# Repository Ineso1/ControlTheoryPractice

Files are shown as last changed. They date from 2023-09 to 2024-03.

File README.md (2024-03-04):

# ControlTheoryPractice

# Linear Axis Control with PID

## Overview
This repository contains the resources and codebase for implementing a PID (Proportional-Integral-Derivative) controller on a linear axis. The project includes simulation models, MATLAB scripts, mechanical design files, Arduino code, and documentation including slides and a PDF report.

## Contents
- **Simulink Models**: Contains the simulation files for the PID control in Simulink.
- **MATLAB Scripts**: Includes MATLAB scripts used for designing and testing the PID controller.
- **Mechanical Files**: CAD files and other mechanical design documents for the linear axis.
- **Arduino Code**: Source code for the Arduino microcontroller to implement the PID control in real hardware.
- **Documentation**: Presentation slides and a detailed PDF report explaining the project's goals, design, and results.

## Getting Started
To get started with this project, you will need MATLAB, Simulink, and an Arduino IDE installed on your computer. Additionally, access to CAD software is necessary to view or modify the mechanical files.

1. Clone the repository to your local machine:
```
git clone https://github.com/Ineso1/Linear-Axis-Control.git
```
2. Open the MATLAB scripts to understand the PID algorithm and simulation setup.
3. Load the Simulink model to simulate the PID control process for the linear axis.
4. Review the mechanical files to understand the physical setup required.
5. Upload the Arduino code to your Arduino device following the setup described in the documentation.
6. Consult the PDF report and slides for a comprehensive overview of the project objectives, design considerations, and outcomes.

## Usage
This project is intended for educational purposes and as a reference for building a PID-controlled linear axis. The code and models provided can be used as a starting point for similar control system projects or adapted to fit specific requirements.



render

planta

ControlBloques

respuestaPID

ControlBloques_lento

respuestaPID_lento

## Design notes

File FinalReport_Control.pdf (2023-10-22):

Final report

Inés Alejandro García Mosqueda A00834571

Oliver Josel Hernández Rebollar A01641922

Paul Enrique Alonso Ramírez A01634608

Analysis of Control Systems

Group 401

Tecnológico de Monterrey, Campus Guadalajara

October 21, 2023

Github Repository: https://github.com/Ineso1/Linear-Axis-Control/tree/main

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
3 Identification of The Plant | 13 Syntonization of The Control | 15 Derivation of The Difference Equation | 22 Implementation of The Control | 23 Results of the Control | 25

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
al | 2
8 Individual | 29

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
# Introduction

In this report we shall address the construction of a plant. Such a plant is a linear axis

which corresponds to a major component in several industrial machines. Furthermore, it is

known that a plant by itself is not useful if we cannot operate it. The main scope of the course is

control theory. Classic and Modern. We did not cover modern control theory, thus we use one of

the most robust and iconic ways of controlling devices, namely, PID controllers. A PID controller

is supposed to modify the system according to a given reference. Naturally, a system has to be

able to identify its current state; therefore, it must receive some sort of feedback. This is known

as a closed-loop system because it is constantly comparing a current state with a desired state

and performing the corresponding modifications to achieve the aforementioned state. The PID

controller is composed of three parts: proportional, integral, and derivative. Each of these parts

play a crucial role in the actuating action because they compensate for disturbances. For

instance, if one exclusively uses a proportional controller, it would be impossible to reach the

reference because it is mathematically impossible. Thereby, we add an integral component

which allows us to approach the reference, but slows down the steady state time. If the system

experiences abrupt disturbances, we must add the derivative part which smooths aggressive

changes in the control. The three parts have a special purpose. However, it is noted that all of

them come with certain costs. To obtain a desired controller, one must carefully tune the gains

based upon a given set of performance characteristics that will be determined by the application

or customer.

All of these things will be developed in the remaining sections of the document. The

main idea is that the reader, if desired, can replicate what we have done. Also, it should be

mentioned that our implementation is not perfect but tolerable. This means that if someone

intends to build a plant, it is recommended that he or she looks for ways to improve. We thank

the professors of the course for their support during the development of the linear axis

# Objective

The objective of this document is to demonstrate one of several applications that the

control apparatus has. We have restricted the application to classical control theory on a linear

axis which is a component from a CNC or computer numerical control. We shall use a PID

controller that was briefly described in previous paragraphs. Also, we apply basic methodologies

from other disciplines such as mechanical, electrical and software engineering. Likewise, we

used some tools from digital control because it is known that one cannot simply port a controller

in continuous time to the microprocessor. Thus, one has to provide an analogous representation

for discrete time. Lastly, we expect to extend the control techniques to complex

electromechanical systems.

# State of The Art

Computer Numerical Control is a way to instruct manufacturing machinery with a

computer. It is a method widely used in the operation of industrial robots. Commonly, the

instructions for the machinery will come from software known as computer-aided design. One

basic type of CNC is point-to-point. Here the tool executes a set of primitive instructions such as

carving a path given its initial and final point. Memory is required to keep track of the performed

commands (Britannica, 2023).

Linear actuators provide, as the name suggests, motion in a straight line. There are several

ways in which one can achieve linear motion. However, we shall devote our attention to the

conversion from rotary motion to linear motion. A way to achieve this is by using screw threads

to a rotary motion source. The present project utilizes a lead screw. A lead screw has helical

threads that are designed for minimum backlash to allow precise positioning. The rotary motion

of the lead screw is translated into the nut’s linear motion. The torque required to move the nut will largely depend on the nature of the application (Figliola & Beasley, 2011). The following

image better depicts the given description.

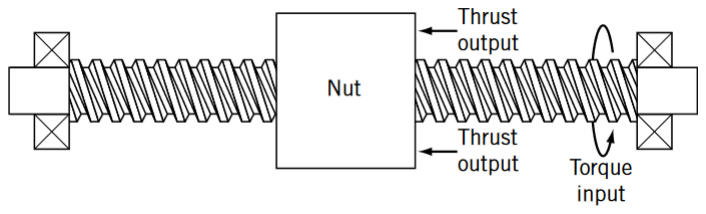
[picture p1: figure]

# Theoretical Framework

As mentioned, lead screws are a way to transmit power in modern machines. They can

generate high forces with a small moment. Also, they are known for providing a really good level

of motion precision. Thus, we see them extensively in applications that use linear actuators or

linear stages. Typically lead screws can operate in two different ways. The first one is by

supplying power to the nut and the other one is by rotating the shaft. Thereby, transferring

power to the nut. In our project, the second way was used in the project. In other words, the

nut’s rotational motion is restricted and the screw shaft rotates. As a consequence the nut

moves along the screw axis, namely, converting the rotary motion into linear motion. There are a

few advantages of lead screws worth noting. Overall, they are cheap and reliable as their

construction is simple; they require little to no maintenance; operations are smooth and reliable;

load capacity is high (Slid, 2022).

H-bridge is a special circuit configuration that allows control over the current source to a load.

This is specially important in motor applications because it is possible to change the behavior of

the motor with an H-bridge. One must be careful always guaranteeing the correct H-bridge

configurations because it is possible to cause a short circuit and damage the component (Franz,

2023). Operation in an H-Bridge is with switches. When using H-Bridge, one must consider at all

times the switches characteristics and the thermal management of the circuit. Ignoring these

properties can lead to operation failure. As mentioned, H-Bridges are heavily utilized in motor

applications, since they can be mixed with the Pulse Width Modulation, hence, controlling the

motor’s speed (Electricity - Magnetism, n.d.).

An encoder is a sensor that retrieves physical variables. As with almost every known sensor,

encoders convert what they sense into an electrical signal that can later be processed and

handled by a piece of software. These devices help to determine the position, speed and

direction. This is achieved by a count that the encoder generates and sends it to a controller.

There are several technologies that an encoder can use to create a signal; for example,

mechanical, magnetic, resistive and optical. Optical is the most common way. Specifically, The

light emitted from a source is periodically interrupted by a disk with holes. These interruptions

are the ones we use to generate the pulses and then know things like the direction of the

encoder, speed, among others (Encoder Products Company, n.d.).

# Construction of The Plant

## Mechanics

The linear shaft is a long rod-shaped tool used to support linear motion, especially

sliding motion. Without it, we wouldn't complete a sliding mechanism with linear power

transmission.

However, manufacturing and selecting the right linear shaft can be complicated. Linear shafts

can have different structures and be made from various materials, depending on the required

properties. With a linear shaft, motion can be guided and adjusted.

The load and specific requirements determine the size and precision of the linear shaft. In linear

power transmission mechanisms, the shaft works alongside an actuator, a support rail, bushings

(ball bearings), etc. In linear power transmission, the actuator typically does all the sliding work,

while the rail, bushings, and linear shafts provide support.

The screw rotates clockwise, causing the shaft, which is essentially a nut on the screw, to move

up and down the screw as the screw rotates. This is what converts the rotational motion of the

electric motor into linear motion. Linear motors have been designed to produce high force at low

speeds and even when stationary. Their design is not based on power but purely on force.

The direct current motor, also known as the direct current motor, is designed to transform

electrical energy into mechanical energy, causing rotary motion. This is made possible thanks to

the magnetic field that composes it, which is perhaps the most important part of the whole

equipment. However, it requires other components to operate effectively, such as the stator,

which serves as mechanical support for the device and holds the machine's poles, which can be

wound with copper wire around an iron core or permanent magnets. The rotor is a cylindrical

instrument with a winding and a core, which are supplied with direct current through the

collector formed by commutator segments. The commutator segments are made of copper and

are in contact with the fixed brushes.

There are two ways to mount the linear shaft: continuous support and end support. Continuous

support shafts are generally used for heavier loads, while those supported at both ends are

used for lighter loads.

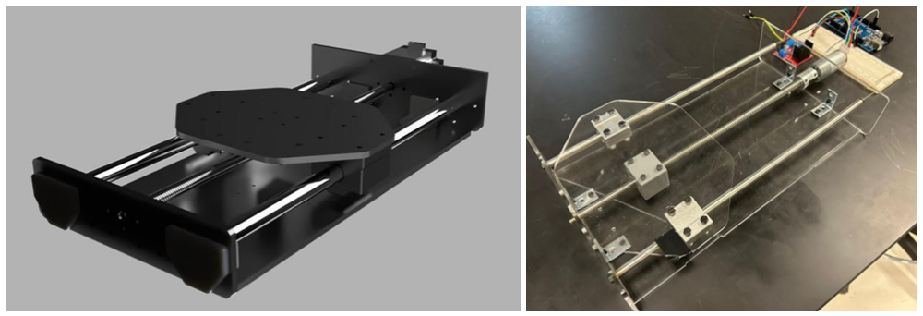
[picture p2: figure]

## Electronics

In the realm of the Linear Axis, where precision is paramount, our electronic components

serve as the central nervous system, orchestrating every facet of movement and control. This

electronic symphony relies on a harmonious ensemble of key components, each playing a

unique and indispensable role.

The L298N motor driver plays a critical role in our Linear Axis Control Project, serving as the

primary component to translate electronic signals into precise physical motion. This integrated

circuit, known for its versatility and reliability, acts as the conductor for the motor's performance.

The main function of the L298N motor driver is essential to our system, serving three main

functions:

- Direction Control: The motor driver manages the motor's direction by reversing the

polarity of the applied voltage to achieve forward or reverse motion.

- Speed Regulation: It allows us to adjust the motor's speed by varying the supplied

voltage, providing us with the capability for precise speed control.

- Current Management: It incorporates current-sensing circuits to prevent overcurrent

conditions, protecting both the motor and the driver itself.

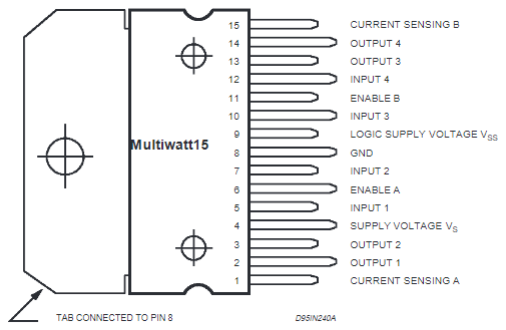
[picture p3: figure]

At the core of our project's electronics is the Arduino Mega, a microcontroller board based on

the ATmega2560. This microcontroller serves as the project's central processing unit, executing

complex control algorithms and facilitating seamless communication with various sensors and

components. The choice of Arduino Mega contributes to the project's user-friendliness and

versatility, making it an ideal candidate for orchestrating the multi-disciplinary aspects of our

linear axis control system.

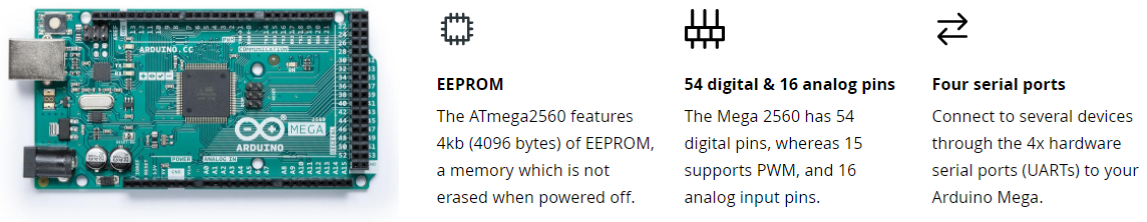
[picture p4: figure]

The motor-reducer assembly seamlessly integrates a motor, reduction gearbox, and encoder, a

trio of components that harmonize to deliver precise control over the linear motion of our axis. At

the core of this assembly is the motor, strategically coupled with a reduction gearbox. Together,

they form a symbiotic relationship, with the motor providing the mechanical power required to

propel the linear motion. The reduction gearbox, with an approximate reduction ratio of 1:45,

transforms the motor's high-speed rotation into the slower, high-torque movement essential for

our project's precision. Nestled within this assembly is the encoder, a sentinel of precision. This

vital component employs Hall Effect technology and boasts a resolution of approximately 493.9

PPR (Pulses Per Revolution) with a ±10% tolerance. Operating within a voltage range of 3.3V to

5V and offering a response frequency of 100 kHz, the encoder delivers real-time feedback that

is instrumental in our pursuit of accuracy. The motor, reduction gearbox, and encoder operate in

tandem to orchestrate the linear motion of our axis. As the motor churns, the gearbox tempers

its high-speed rotation, allowing for controlled movement. Simultaneously, the encoder diligently

records every aspect of this motion—position, speed, and direction. This trove of data serves as

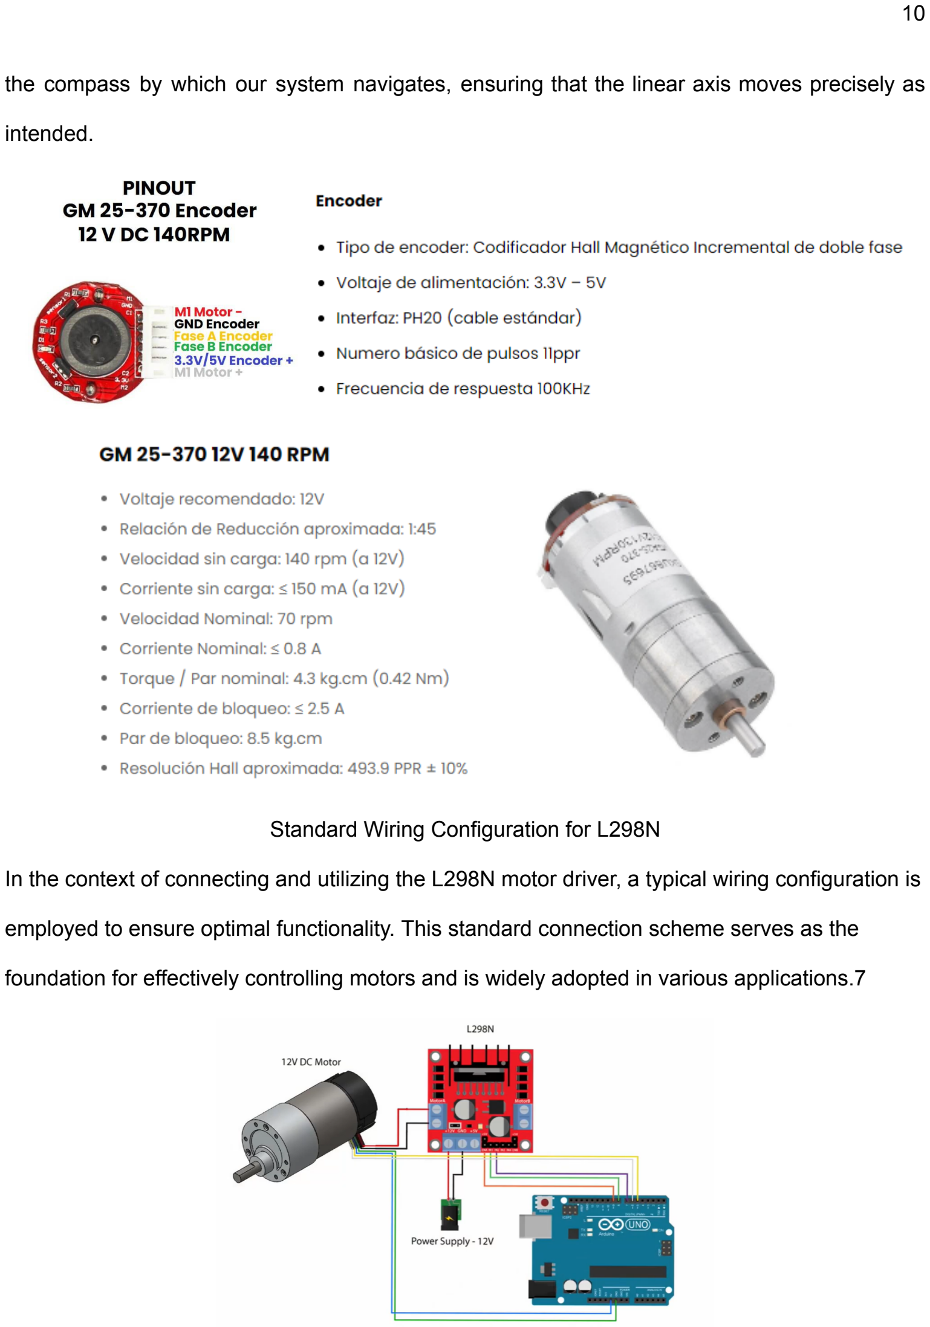
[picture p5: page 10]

the compass by which our system navigates, ensuring that the linear axis moves precisely as

intended.

Standard Wiring Configuration for L298N

In the context of connecting and utilizing the L298N motor driver, a typical wiring configuration is

employed to ensure optimal functionality. This standard connection scheme serves as the

foundation for effectively controlling motors and is widely adopted in various applications.7

## Software

The software we developed is quite simple because we were instructed to use an

Arduino which is known for being user friendly. We wanted to increase the portability and

robustness of our design, so we implemented a class called PositionMotorControl. This class

has five methods for orchestrating the motor’s behavior. The constructor will retrieve all the

information for the member functions. Initialization method will send the constructor’s data to the

Arduino. Control method will be rotating the shaft based upon an error computed using the

number of pulses. Set Target Position receives the desired position in the number of pulses. Get

Current Position returns the current position attribute and Set Cero establishes what will be

taken as the reference, namely, the origin. Attributes declared with the volatile qualifier are used

in the interruption called Handle Encoder. This private function member reads the encoder in

real time and updates things like current position and the motor’s direction. It is declared as

static and thus uses a pointer to be called. At the beginning of the main program we create a

motor instance, then set the baud rate to communicate with the microcontroller. Lastly we enter

the loop and read the Serial Monitor to receive input from the user, if that does not happen, we

print the position. Later the control method is called and moves the nut to the desired position.

The reason of this implementation is:

- Initialization: One of the key features of the 'PositionMotorControl' class is its initialization

process. We utilize the 'init()' method to initialize the motor and encoder pins, thereby

configuring the necessary parameters for control. This step is vital in preparing the

system for precise motion control.

- Control Methods: The class incorporates various control methods, notably 'control()' and

'controlPID()', which enable us to fine-tune the motor's behavior to meet our specific needs. These methods play a pivotal role in ensuring the motor's responsiveness and

adaptability to different control strategies.

- Position and Velocity: Within our software, we can set the target position, monitor the

current position, and adjust the motor's velocity as required. This capability allows us to

precisely control the motion of our linear axis, making it responsive to real-world

demands.

- Error Handling: Error handling is an integral part of our software. We utilize variables

such as 'error' and 'errores' to precisely manage and respond to any deviations from the

desired path. These mechanisms contribute to the system's accuracy and robustness.

- Hardware Integration: The class seamlessly integrates with the hardware by working

with motor pins, supporting encoder feedback, and incorporating mechanical constants.

This integration ensures accurate and controlled motion. Mechanical constants such as

gear ratios and encoder resolutions are considered to convert between pulses and

real-world positions.

- Interrupt Handling: Our software employs interrupt-driven functions to manage encoder

changes efficiently. By doing so, we enhance the overall efficiency of our system,

enabling rapid response to position changes and contributing to the system's stability.

- Custom Libraries: To streamline and encapsulate the functionality, we have developed

custom libraries, 'PositionMotorControl.h' and 'PositionMotorControl.cpp'. These libraries

simplify the integration of motor control into our project and promote code modularity.

The following is a high-level description of the main program. The control method is responsible

for rotating the shaft based on an error computed using the number of pulses.

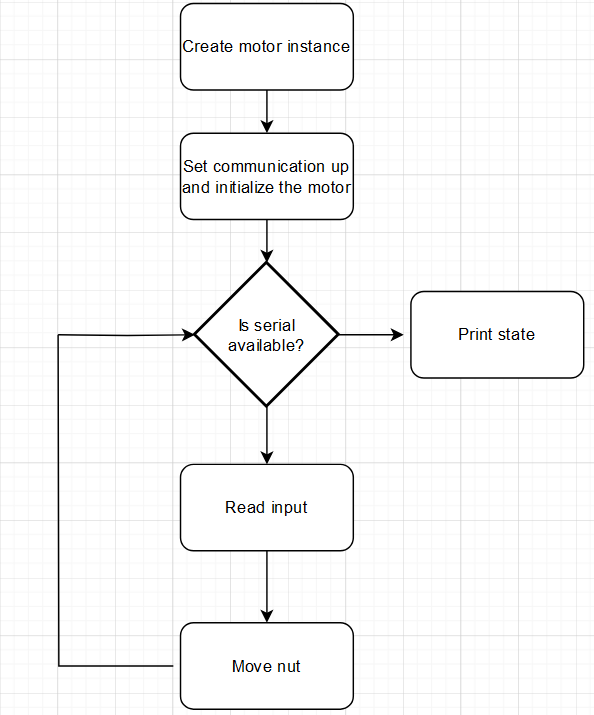
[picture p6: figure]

# Implementation of The System

## Identification of The Plant

Identifying the plant means creating a mathematical or empirical model that describes the

behavior of the system. This model helps us understand how the system responds to different

inputs and disturbances. Without a proper model, it's challenging to predict or explain system

behavior accurately. Knowing the plant is fundamental for designing effective control systems.

Engineers need to understand the dynamics of the system to design controllers that can

regulate it optimally. Control algorithms often rely on an accurate model of the plant to determine

control actions. This helps us to optimize the performance of the system. By understanding the

plant's response characteristics, we can fine-tune control strategies to achieve desired

performance metrics, such as stability, speed, accuracy, and robustness. Plant identification

allows us to optimize the performance of the system. By understanding the plant's response

characteristics, we can fine-tune control strategies to achieve desired performance metrics,

such as stability, speed, accuracy, and robustness.

We implemented a systematic and data-driven process, leveraging carefully designed code to

uncover the dynamic behavior of our motor.

Data Acquisition

The initial phase of our plant identification process entailed the collection of extensive data. We

aimed to create a comprehensive dataset that allowed us to explore how the motor system

responded to varying input signals. To accomplish this, we employed a controlled

experimentation approach. We applied a range of PWM (Pulse Width Modulation) signals to the

motor while simultaneously measuring and recording the corresponding encoder output. This

process was carried out at consistent time intervals to ensure that we obtained a precise and

reliable dataset. The data acquisition step was pivotal in capturing the dynamic response of our

motor system under a variety of operating conditions. It allowed us to observe the system's

behavior as it adapted to different control inputs, providing valuable insights into its

characteristics.

Regression Analysis

With our dataset in hand, we turned to the tools offered by MATLAB's System Identification

Toolbox. This software environment provided us with the means to perform advanced data

analysis, model fitting, and system identification. Through the application of regression analysis

techniques, we embarked on the task of approximating the plant function that governs the behavior of our motor system. This function represents the mathematical relationship between

the input (PWM signals) and the output (encoder responses) of the system. Our objective was

to develop a mathematical model that could accurately describe and predict the motor's

behavior under various conditions. The regression analysis process involved the exploration of

different model structures, identification of model parameters, and the validation of the resulting

model against the acquired data. By iteratively refining the model, we sought to achieve a high

level of accuracy in representing the dynamic behavior of the motor system.

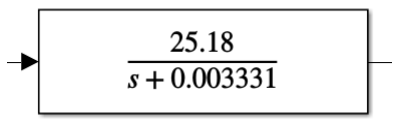
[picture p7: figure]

Access to the Code Repository for characterization of the plant

For a comprehensive understanding of our project's code and implementation, you can access

the complete source code and related resources in our GitHub repository. The code is available

at the following link:

GitHub Repository - Code for Characterization of Angular Velocity:

https://github.com/Ineso1/Linear-Axis-Control/tree/main/ControlProgram/CaracterizacionVelocid

adAngular (https://github.com/Ineso1/Linear-Axis-Control/tree/main/ControlProgram/CaracterizacionVelocidadAngular)

## Syntonization of The Control

In the realm of control systems, achieving optimal performance often necessitates the careful

adjustment and tuning of control parameters. This process, known as control tuning or

syntonization, is a pivotal step in ensuring that the control system responds accurately and

effectively to the desired setpoints and disturbances.

Importance of Control Syntonization

- Enhanced Performance: Accurate control parameter tuning can lead to improved system

performance, enabling faster response times, reduced settling times, and more precise

control of the system's behavior.

- Stability and Robustness: Proper syntonization ensures that the control system remains

stable under various operating conditions and disturbances. It prevents issues such as

overshoot, oscillations, and instability.

- Minimized Energy Consumption: Well-tuned control systems can operate more

efficiently, consuming less energy and reducing operational costs.

- Adaptation to Changing Conditions: As real-world conditions change, the control system

needs to adapt. Control syntonization allows the system to adjust to new parameters and

maintain optimal performance.

- Improved Safety: In safety-critical systems, accurate syntonization is imperative to

prevent dangerous and unexpected behavior.

- Control parameter tuning typically involves adjusting variables like proportional gain (Kp),

integral gain (Ki), and derivative gain (Kd) in a PID (Proportional-Integral-Derivative)

controller. The specific methodology and approach to syntonization depend on the

control algorithm and the characteristics of the plant.

Methods of Control Syntonization

There are various methods and techniques for control syntonization, including:

- Manual Tuning: In this method, we adjust control parameters manually based on their

knowledge and experience. It's a trial-and-error approach that may require multiple

iterations to achieve optimal results.

- Ziegler-Nichols Method: This method provides systematic guidelines for tuning PID

controllers. It involves identifying the ultimate gain and ultimate period from the system's

response to a step input.

- Frequency Response Analysis: Using frequency response techniques, we can analyze

the system's behavior to determine the optimal control parameters.

- Optimization Algorithms: Advanced techniques, such as gradient descent or genetic

algorithms, can be used to automate the syntonization process. These methods aim to

find optimal parameter values efficiently.

Our approach

In our project, we employed an analytical approach for the syntonization of the PID

(Proportional-Integral-Derivative) controller. The goal was to fine-tune the control parameters to

achieve the desired system response. Our approach primarily centered around using the

concepts of maximum impulse and steady-state time, and ultimately, partial fractions

decomposition.

To begin the syntonization process, we identified the system's ultimate gain. The ultimate gain is

the magnitude of the control signal that, when applied as a step input, induces sustained

oscillations in the system's response. The maximum impulse is a crucial parameter for the

syntonization of the controller. Concurrently, we determined the steady-state time, which

represents the period of one complete oscillation cycle under the influence of the maximum

impulse parameter. The steady-state time provides insight into the system's oscillatory behavior.

Syntonization Through Partial Fractions Decomposition

The ultimate gain and steady-state time values served as foundational information for the

syntonization process. We leveraged these parameters to derive a transfer function that accurately represented the dynamics of the system. This transfer function was critical for tuning

the PID controller. The syntonization process involved expressing the system's response as a

sum of first-order and second-order transfer functions, represented through partial fractions

decomposition. By decomposing the system into these simpler components, we could better

understand and control its response. Using the derived transfer function, we adjusted the control

parameters; Proportional Gain (Kp), Integral Time (Ti), and Derivative Time (Td to achieve the

desired system response. The insights gained from the decomposition guided us in selecting

appropriate values for these parameters to optimize the system's performance.

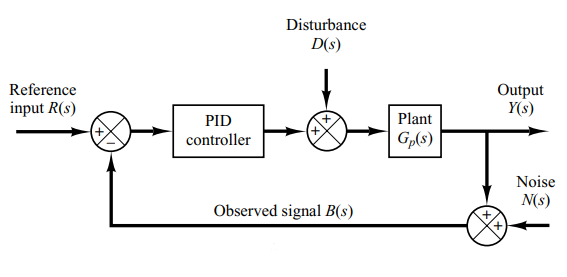
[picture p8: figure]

Advantages of Analytical Syntonization

- Theoretical Foundation: This analytical approach to syntonization is firmly grounded in

control theory and system dynamics, providing a strong theoretical basis for tuning the

controller.

- Precise Control: By using Ku and Tu to derive the transfer function and employing partial

fractions decomposition, we were able to fine-tune the control parameters with a high

degree of precision.

- Efficiency: The analytical approach is efficient and eliminates the need for extensive

trial-and-error tuning, resulting in a more streamlined and systematic syntonization

process.

In the subsequent section, we will detail the specific steps taken and results achieved through

this analytical syntonization approach. This will provide a comprehensive understanding of how

we optimized the control system to meet our project's requirements.

Certainly, you can include the second approach you used for PID tuning with MATLAB Simulink

in your report:

Alternative Approach: MATLAB Simulink PID Tuning

In addition to our analytical approach, we employed an alternative method for synchronizing the

PID (Proportional-Integral-Derivative) controller. This alternative approach involved leveraging

the capabilities of MATLAB Simulink, a powerful tool for system modeling and control design.

Using MATLAB Simulink for PID Tuning

Model Representation: In this approach, we first created a dynamic model of our system within

MATLAB Simulink. This model encapsulated the plant's behavior and its interaction with the PID

controller. In this implementation we added a PID controller block to our Simulink model. This

block allowed us to easily adjust the controller's parameters, including the Proportional Gain

(Kp), Integral Time (Ti), and Derivative Time (Td). MATLAB Simulink provides a suite of

automated tuning tools that simplify the process of optimizing the control parameters. These

tools can be especially valuable when dealing with complex systems or when a quick and efficient tuning process is required. With the PID controller block and automated tuning tools in

place, we conducted simulations to observe the system's response under various conditions.

MATLAB Simulink allowed us to visualize and analyze the system's behavior, helping us identify

the optimal control parameters. The flexibility of MATLAB Simulink allowed us to iteratively

refine the control parameters until the system's response aligned with our project's

requirements. We could easily adjust the gains and time constants in real-time during the

simulation.

Advantages of the MATLAB Simulink Approach

- User-Friendly Interface: MATLAB Simulink offers an intuitive and user-friendly interface

for control system design and tuning, making it accessible even to those with limited

control engineering expertise.

- Efficiency: The automated tuning tools within MATLAB Simulink can expedite the tuning

process, saving time and effort, especially in cases where a complex system requires

quick syntonization.

- Visual Feedback: The ability to visualize and analyze the system's response in real-time

is a significant advantage. It allows for a more intuitive understanding of the system's

behavior and control performance.

- Robustness: The automated tools in MATLAB Simulink are equipped to handle various

system responses, including overshoot, oscillations, and settling times. This ensures

robust control parameter tuning.

For an in-depth exploration of our control analysis, including detailed models, simulations, and

results, we invite you to review the complete set of resources available in our GitHub repository.

These resources provide comprehensive insights into our control strategies and methodologies,

offering a deeper understanding of our project's control system.

Unset

Access to the Code Repository for PID Analysis and Tuning

GitHub Repository - Analysis of Control:

https://github.com/Ineso1/Linear-Axis-Control/tree/main/Analisis%20de%20Control

Our analytical approach MATLAB code

#Caracteristicas del control en velocidad angular

Mp = 0.15;
psib = sqrt(((log(Mp))^2 / (pi^2))/(1 - ((log(Mp))^2 / (pi^2)))) ts = 5;
omeganb = 3/(psib*ts)
Q = 2*psib*omeganb;
T = omeganb;
(-Q + sqrt(Q^2 - 4*T))/2;
p1 = 10*Q;
A = Q + p1;
B = T + p1*Q;
C = p1*T;

#Funcio de planta y coeficientes PID

omegan = 0.01;
psi = 3;
2*psi*omegan;

kd = ((A/omegan) - 2*psi)/omegan kp = B/(omegan^2) - 1
ki = C/(omegan^2)

integ = ki/kp
deriv = kd/kp

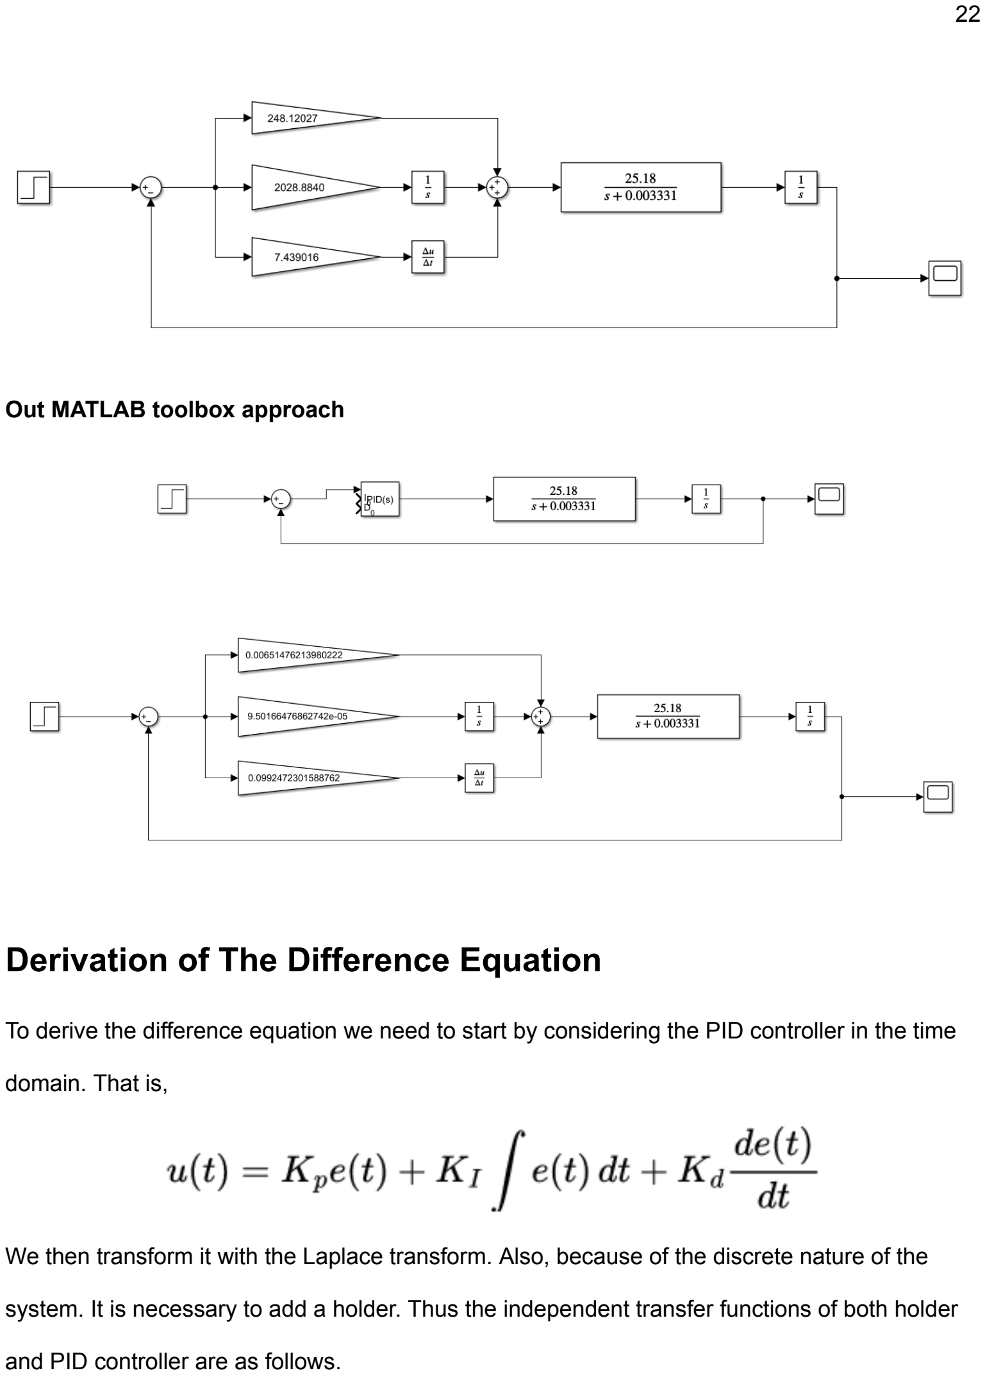
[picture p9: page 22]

Out MATLAB toolbox approach

## Derivation of The Difference Equation

To derive the difference equation we need to start by considering the PID controller in the time

domain. That is,

We then transform it with the Laplace transform. Also, because of the discrete nature of the

system. It is necessary to add a holder. Thus the independent transfer functions of both holder

and PID controller are as follows.

By using some algebra of diagrams. The output of a block is the product of the transfer function

and the input signal. Therefore, the product of both holder and PID controller is the resulting

equation.

At this point it is convenient to use the z transform because we are dealing with a discrete

implementation, so it looks like this

After the transform and some algebraic manipulation we arrive to the PID expression in

z-domain

By getting rid of the fractions and separating CV and E on different sides of the equation we

arrive to the following expression

Then, by using known formulas we perform the inverse transform and arrive to the known

difference equation form

C/C++

## Implementation of The Control

Our linear axis control system incorporates a PID (Proportional-Integral-Derivative) controller to

precisely regulate the motion of the linear axis. The PID controller plays a crucial role in

achieving the desired position while maintaining stability and responsiveness.

void PositionMotorControl::controlPID(){
error = targetPosition - (currentPosition * 2 * 3.1416 / 493.9); errores[1] = errores[0];
errores[2] = errores[1];
errores[0] = error;
prevPwm = motorSpeed;

double kp = 248;
double ki = 2300;
double kd = 7.44;
double a = (kp + kd/0.02) * errores[0];
double b = (-kp + (ki*0.02) - (2*kd/0.02)) * errores[1]; double c = (kd/0.02) * errores[2];

int pwmSpeed = prevPwm + a + b + c;
motorSpeed = pwmSpeed;

// Comparison between direction and velocity if (error <= -1) {
motorDirection = 1; // Move forward
}
else if (error >= 1) {
motorDirection = -1; // Move backward }
else {
motorDirection = 0; // Stop
pwmSpeed = 0;
}

// Motor's control
analogWrite(motorPin1, motorSpeed); digitalWrite(motorPin2, motorDirection == -1 ? HIGH : LOW); digitalWrite(motorPin3, motorDirection == 1 ? HIGH : LOW);

}

PID Parameters:

- kp (Proportional Gain): 248
- ki (Integral Gain): 2300
- kd (Derivative Gain): 7.44

PID Components:

- a: Proportional component
- b: Integral component
- c: Derivative component

This PID controller computes a new PWM speed for the motor based on the current error and

the stored error values. It adjusts the motor direction to move towards the target position while

considering the error's magnitude.

The PID implementation in our code ensures precise and stable control of the linear axis,

enabling it to accurately follow the desired trajectory. The fine-tuned PID parameters are a result

of our syntonization process, as described in previous sections. The flexibility to adjust these

parameters allows us to tailor the control system to meet specific performance requirements.

Access to the Code Repository for The full Linear Axis Control Code

For a comprehensive view of the project's implementation details, including the codebase,

models, and system setup, please explore the complete set of resources available in our GitHub

repository:

GitHub Repository - Implementation Section:

https://github.com/Ineso1/Linear-Axis-Control/tree/main/ControlProgram/LinearAxisControl_v2/C

ontrolEjeLineal_v2 (https://github.com/Ineso1/Linear-Axis-Control/tree/main/ControlProgram/LinearAxisControl_v2/ControlEjeLineal_v2)

## Results of the Control

Our PID control approach for the linear axis has yielded notable outcomes, each with distinct

characteristics. These results highlight the impact of control syntonization on the performance of

our system. We Analyze the achievements of both approaches, emphasizing the advantages

and disadvantages of quick and slow response times.

Quick Response Approach (Maximum Impulse: 15%, Steady-State Response: 0.4 seconds)

Slower Response Approach (Maximum Impulse: 1%, Steady-State Response: 2 seconds)

Advantages of a Quick Response:

- Precision: The quick response approach offers precise control, allowing the linear axis to

closely follow the desired trajectory with minimal deviation.

- Reduced Settling Time: The rapid steady-state response, achieved within 0.4 seconds,

results in a shorter settling time. This is particularly advantageous when the system

needs to reach and maintain a specific position swiftly.

- Enhanced Responsiveness: Quick response times make the system highly responsive to

changes in the input or disturbances, enhancing its ability to adapt to dynamic

conditions.

Disadvantages of a Quick Response:

- Risk of Overshoot: A rapid response may lead to overshooting, where the system briefly

exceeds the desired position before stabilizing. This can introduce oscillations or

instability.

- Increased Energy Consumption: Achieving a quick response may require higher control

efforts, potentially leading to increased energy consumption.

- Potential for Reduced System Longevity: High-speed movements can contribute to wear

and tear on mechanical components, which may reduce the system's overall longevity.

Advantages of a Slower Response:

- Stability: The slower response approach prioritizes stability, minimizing the risk of

overshoot and oscillations. This can be advantageous in systems where stability is

critical.

- Reduced Energy Consumption: Slower responses typically require less energy, making

them energy-efficient and cost-effective in the long run.

- Enhanced System Durability: Reduced stress on mechanical components can prolong

the system's lifespan, contributing to its long-term reliability.

Disadvantages of a Slower Response:

- Reduced Precision: Slower responses may result in less precise control, particularly in

applications where rapid, precise movements are required.

- Longer Settling Time: A slower steady-state response with a 2 second settling time may

not be suitable for applications that demand rapid positioning or immediate responses to

disturbances.

- Limited Responsiveness: Slower responses make the system less adaptable to dynamic

changes, potentially affecting its ability to respond swiftly to new conditions.

Balancing Act

The choice between a quick response and a slower response is a delicate balancing act. The

optimal approach depends on the specific requirements and constraints of the application. In

some cases, precision and rapid response are paramount, while in others, stability and energy

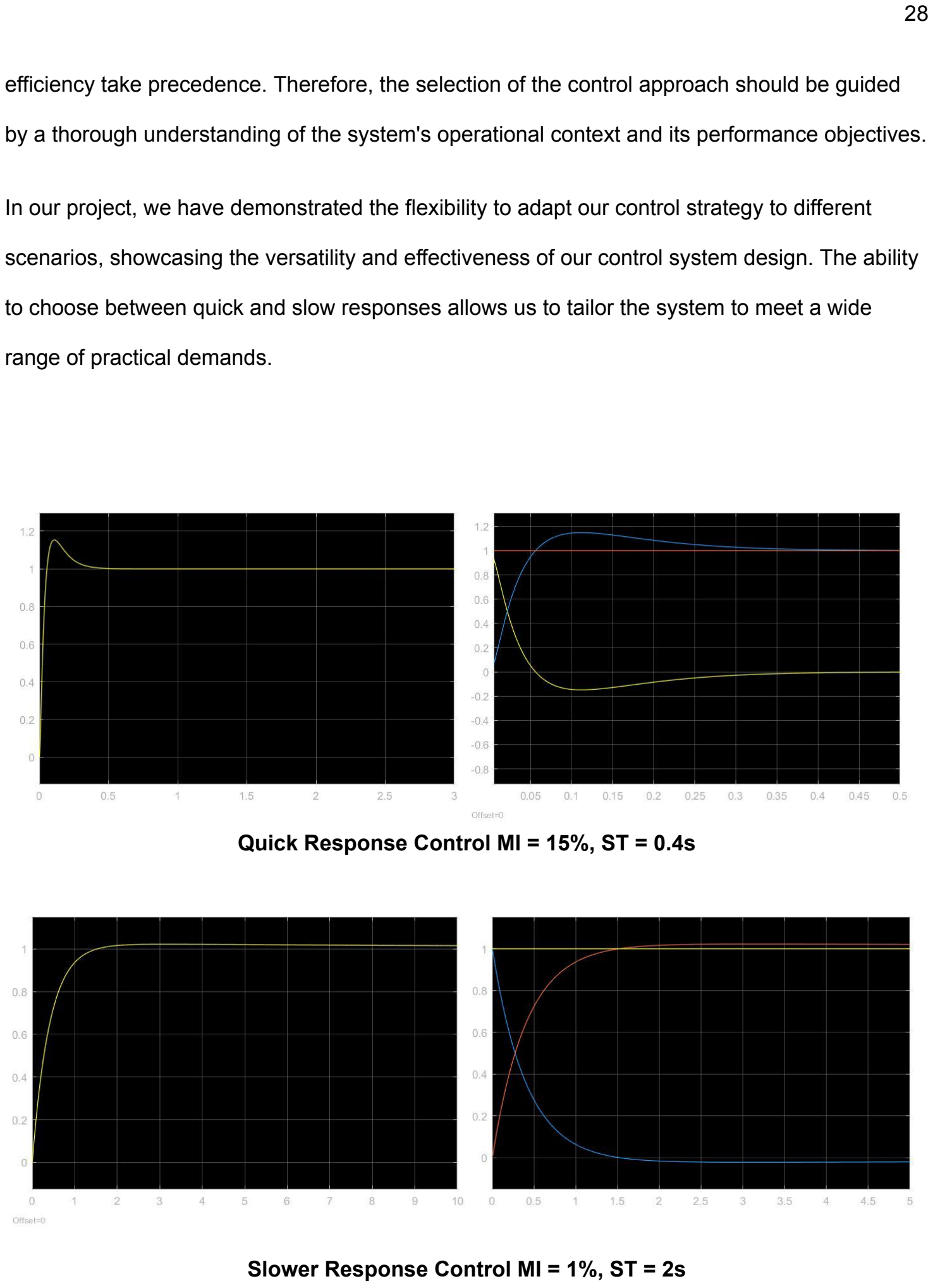
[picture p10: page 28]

efficiency take precedence. Therefore, the selection of the control approach should be guided

by a thorough understanding of the system's operational context and its performance objectives.

In our project, we have demonstrated the flexibility to adapt our control strategy to different

scenarios, showcasing the versatility and effectiveness of our control system design. The ability

to choose between quick and slow responses allows us to tailor the system to meet a wide

range of practical demands.

Quick Response Control MI = 15%, ST = 0.4s

Slower Response Control MI = 1%, ST = 2s

# Conclusion

## General

The control, mechanics and electronics of a linear axis operate to achieve precision,

speed and reliability in numerous applications ranging from industrial machinery to advanced

robotics. Mechanics provide the structural foundation and movement capabilities, driven by

electronics ensuring precise energy delivery and timing. The control system receives input from

the user or system, converts them into commands for the electronics and mechanics to execute.

In conclusion, the perfect integration of these three components is essential. Its collaborative

operation ensures efficient and accurate performance of a linear axis, which is vital to

maintaining the high standards required in today's technologically advanced environment.

## Individual

Oliver In my understanding of the control, mechanics, and electronics of a linear axis,

they work together to deliver precision, speed, and reliability in a broad spectrum of

applications, from industrial machines to cutting-edge robotics. While the mechanics give the

structural backbone and movement capabilities, the electronics are responsible for ensuring

precise power transmission and synchronization. As for the control system, I see it as the brain

that takes in user or system inputs and turns them into actionable instructions for the mechanics

and electronics. To sum it up, I believe that the flawless integration of these three elements is

critical. Their collective function ensures the efficient and precise operation of a linear axis,

which I consider essential in the high-standard, tech-driven environments of today.

Inés I've acquired a profound understanding of control theory and its practical

applications in digital systems, particularly in the discrete-time domain. The journey involved

bridging the gap between theory and real world implementation, a valuable skill in the realm of

engineering. From PID controllers to plant identification and syntonization, I've learned how to harness mathematical principles to achieve precise control. I now appreciate the beauty of

control theory in creating efficient, stable, and responsive systems. This experience has

provided me with a strong foundation in translating complex mathematical concepts into code,

enabling me to bring control theory to life in my projects. As I move forward, I feel well-equipped

to tackle diverse engineering challenges with a solid grasp of mathematics, the theory, and the

practical application of control systems in digital systems and discrete-time environments.

Paul I have learned several things over the course of 10 weeks. Most importantly, I have

realized all the things that can be done with control theory. I believe that a linear axis is just one

of the many applications of control. I am excited to see what other things can be done,

especially, in the realm of robotics which is an important and emerging field. As far as I am

concerned there are several subfields in control theory given the nature of several dynamical

systems. There will be times when it is not possible to linearize a system, so we will be forced to

look for generalized ways of modeling a system. Nevertheless, I presume this was a fairly good

introduction to control theory and some of its applications. I look forward to learning more on the

subject, and luckily enough with a more theoretical approach, as I strongly believe it is essential

to comprehend the area.

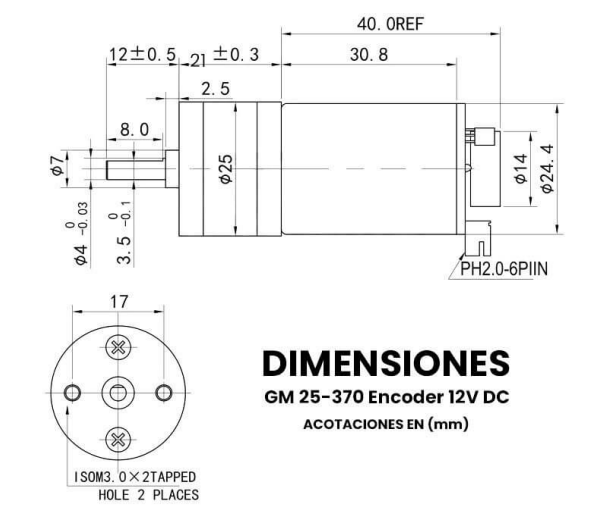
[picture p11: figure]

https://uelectronics.com/producto/gm-25-370-motor-con-encoder-12v-dc-140rpm-330rpm/

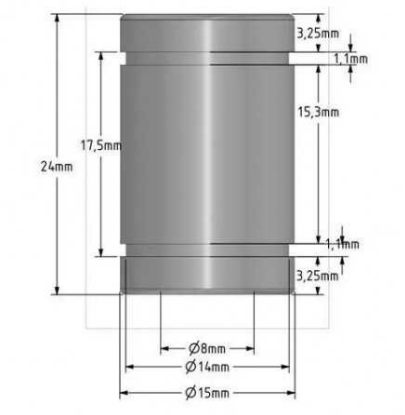
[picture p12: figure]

https://uelectronics.com/producto/balero-rodamiento-lineal-lm8uu-de-8mm-3d-cnc/

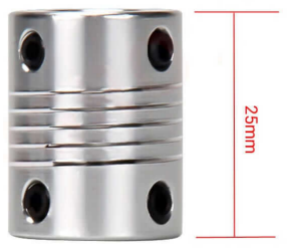
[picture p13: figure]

Etiquetas: Acoplador Nema, cople, Cople D18L25, cople flexible, Cople Flexible 5x5mm, Cople Flexible 5x8mm, Cople Flexible 6.35x8mm, Cople Flexible 8x10mm, Cople Flexible 8x8mm, Cople Flexible D18L25, D18L25, Piezas y Accesorios 3D CNC https://uelectronics.com/producto/cople-flexible-d18l25-nema-acoplador/

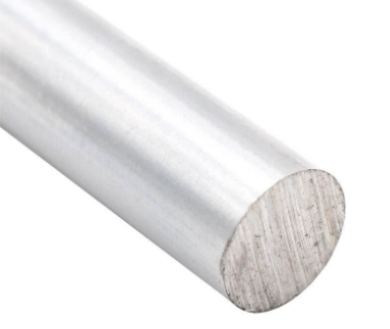
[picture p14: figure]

Varilla Lisa 8mm 60cm para Impresora 3D/CNC https://uelectronics.com/producto/varilla-lisa-8mm-para-impresora-3d-cnc/

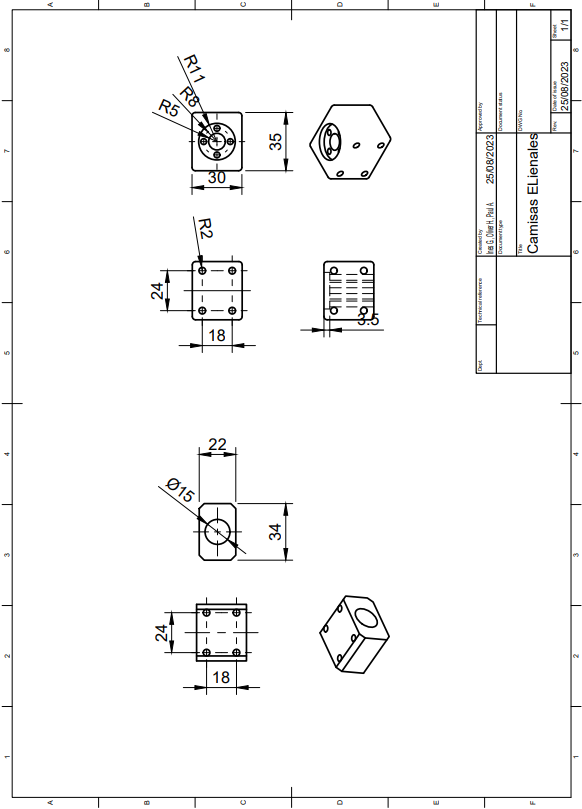
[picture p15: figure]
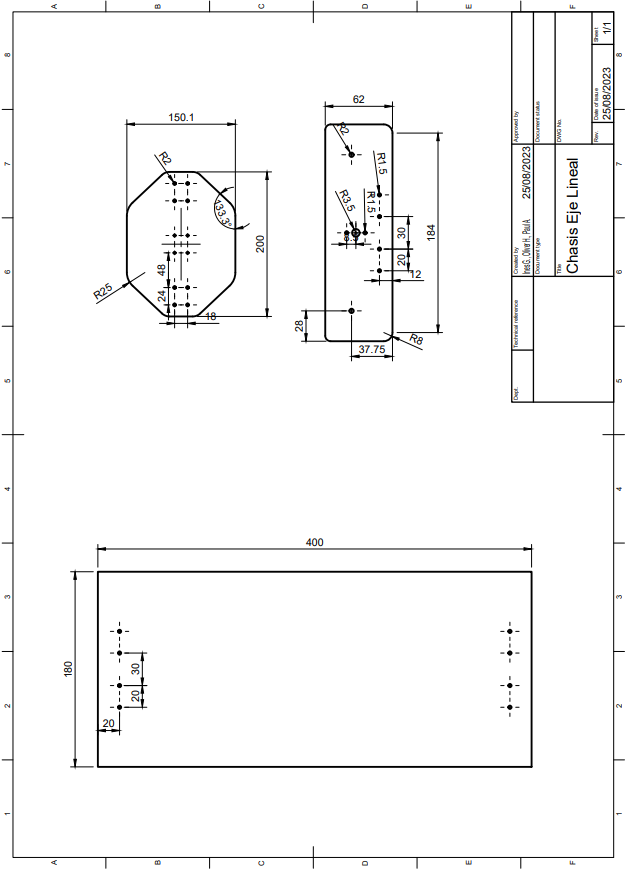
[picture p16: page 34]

# References

Britannica. (2023, May 28). Computer Numerical Control.

https://www.britannica.com/technology/numerical-control

Electricity - Magnetism. (n.d.). H-Bridges. https://www.electricity-magnetism.org/h-bridges/

Encoder Products Company. (n.d.). What is an encoder?.

https://www.encoder.com/article-what-is-an-encoder

Figliola, R., & Beasley, D. (2011). Theory and Design for Mechanical Measurements. John Wiley

& Sons, Inc.

Franz, K. (2023, April 18). What Is an H-Bridge?. https://digilent.com/blog/what-is-an-h-bridge/

Slid Siim. (2022, January 24). Lead Screws Explained. https://fractory.com/lead-screws/

Mega, A. (s/f). Arduino® MEGA 2560 Rev3. Arduino.cc. Recuperado el 10 de septiembre de

2023, de https://docs.arduino.cc/resources/datasheets/A000067-datasheet.pdf

Mega, A. (s/f). Arduino® MEGA 2560 Rev3. Arduino.cc. Recuperado el 10 de septiembre de

2023, de https://docs.arduino.cc/resources/datasheets/A000067-datasheet.pdf

Mega, A. (s/f). Arduino® MEGA 2560 Rev3. Arduino.cc. Recuperado el 10 de septiembre de

2023, de https://docs.arduino.cc/resources/datasheets/A000067-datasheet.pdf

# Appendix

## Code

https://github.com/Ineso1/Linear-Axis-Control/tree/main

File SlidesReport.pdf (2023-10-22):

## Analysis of Control Systems

Ines Garcia | Oliver Hernandez | Paul Ramirez

Tecnologico de Monterrey, Campus Guadalajara

October 20, 2023

Ines Garcia, Oliver Hernandez, Paul Ramirez | Tecnologico de Monterrey, Campus Guadalajara

Analysis of Control Systems

1 | Introduction
2 | Construction of The Plant
3 | Implementation of The System
4 | Conclusion

During the course we developed a linear axis as well as its control. Previously, we presented the construction of the plant, so now we shall devote this presentation mainly to the design and implementation of the PID control. Lastly, we will provide some of the needed theory to understand the decisions behind our plant.

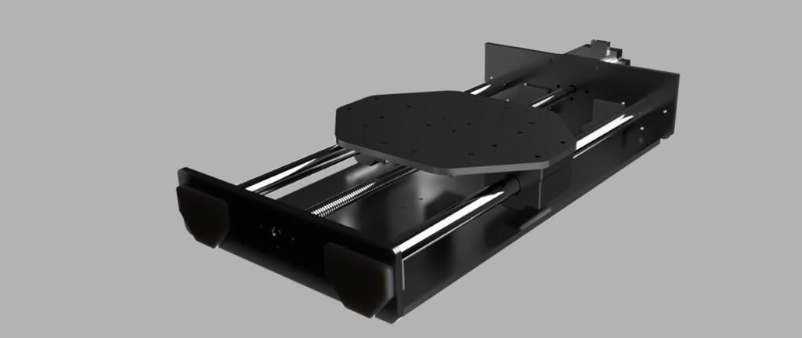
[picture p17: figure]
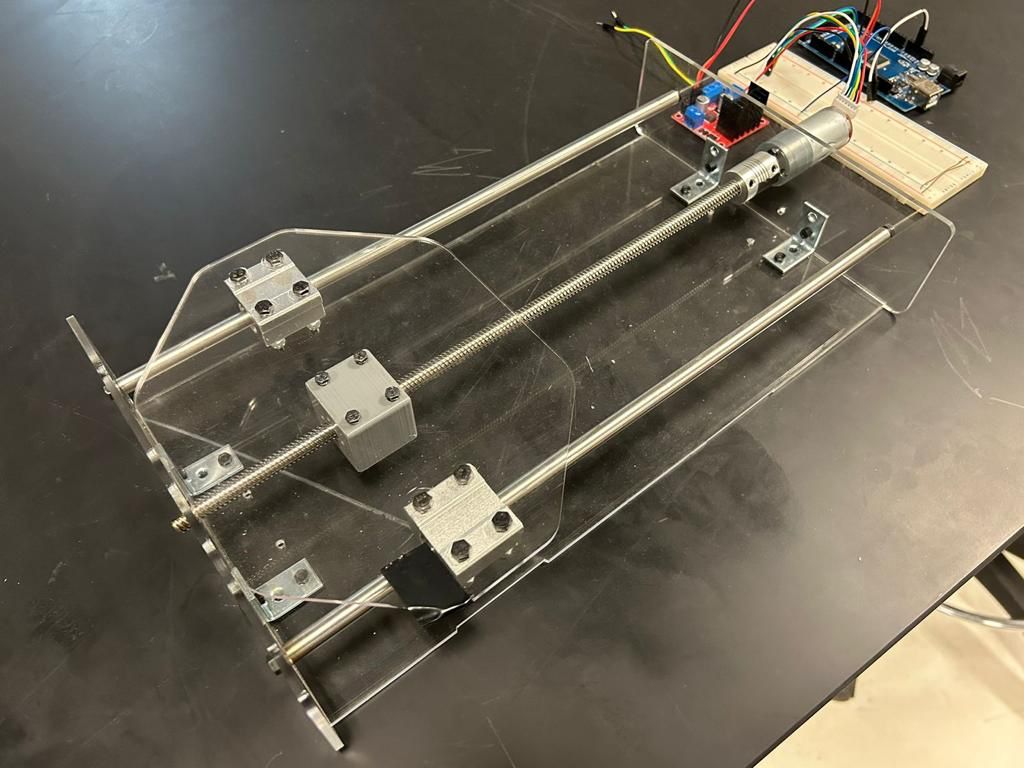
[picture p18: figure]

Figure: Render and Photograph of the Constructed Plant

Linear Shaft: The linear shaft is a long rod-shaped component that supports linear motion and power transmission. It guides and adjusts motion
Size and Precision: The size and precision of the linear shaft are determined by factors such as the load and specific requirements of our application.
Screw Mechanism: Our system features a screw mechanism that converts the rotational motion of the electric motor into linear motion.
Mounting Options: Linear shafts can be mounted in two ways: continuous support and end support. The choice depends on the load and application

12-Volt Motor: Our project features a robust 12-volt motor L298N Motor Controller: We’ve integrated the L298N motor controller
Arduino Mega: The Arduino Mega serves as our computational powerhouse
Encoder: The motor is equipped with an encoder, delivering real-time feedback on position and velocity.

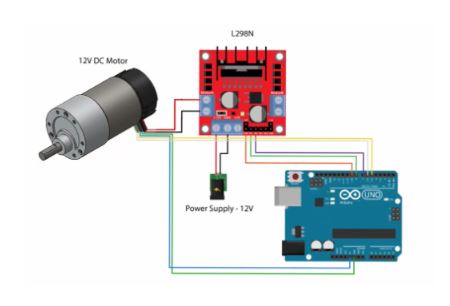
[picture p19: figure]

Figure: Schematic Diagram of Our Electronics Ines Garcia, Oliver Hernandez, Paul Ramirez | Tecnologico de Monterrey, Campus Guadalajara

Purpose: The ‘PositionMotorControl‘ class is designed to provide advanced control for our linear axis. It allows us to set and control the position, velocity, and direction of the motor. Initialization: The class features methods like ‘init()‘ to initialize the motor and encoder pins, setting up the necessary parameters for control.
Control Methods: With methods like ‘control()‘ and ‘controlPID()‘, we can fine-tune the motor’s behavior, making it responsive to our specific needs.

Position and Velocity: The class enables us to set the target position, monitor the current position, and adjust the motor’s velocity as required.

Error Handling: It incorporates error handling mechanisms, such as the ‘error‘ and ‘errores‘ variables, for precise control and responsiveness.
Hardware Integration: The class interacts with the motor through pins, supports encoder feedback, and leverages mechanical constants to ensure accurate motion. Interrupt Handling: To manage encoder changes, the class uses interrupt-driven functions, enhancing the overall efficiency of the system.
Custom Libraries: We’ve developed custom libraries, ‘PositionMotorControl.h‘ and ‘PositionMotorControl.cpp‘, to encapsulate the functionality and simplify integration into our project.

In our project, we implemented a system identification process to uncover the characteristics of our motor system. To achieve this, we utilized a carefully designed code that randomized the PWM signals applied to the motor while simultaneously measuring the encoder output at consistent time intervals.
Data Acquisition: The first step involved collecting extensive data by applying varying PWM inputs and capturing corresponding encoder responses.
Regression Analysis: With our dataset in hand, we harnessed the power of MATLAB’s System Identification Toolbox. Through regression analysis, we approximated the plant function that governs the behavior of our motor system.

Consider the PID controller with an s-domain transfer function

U(s)
X(s)

= Gc (s) = KP +

KI
s

+ KDs

We can determine a digital implementation of this controller using a discrete approximation for the derivative and integration. For the time derivative, we use the backward difference rule

u(kT) = dx
dt
t=kT

=

1
T

(x(kT) − x((k − 1)T))

The z-transform of the equation is then

U(z) = 1 − z

−1

T

X(z) = z − 1
Tz X(z)

The integration of x(t) can be represented by the forward rectangular integration at t = kT as

u(kT) = u((k − 1)T) + Tx(kT)

where u(kT) is the output of the integration at t = kT. The z-transform is

U(z) = z

−1U(z) + TX(z)

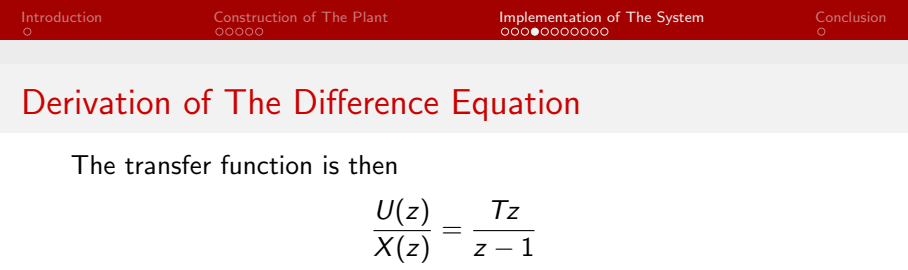
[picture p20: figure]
Derivation of The Difference Equation; The transfer function is then

Hence, the z-domain transfer function of the PID controller is

Gc (z) = KP + KI

Tz
z − 1

+ KD

z − 1
Tz

The complete difference equation algorithm that provides the PID controller is obtained by adding the three terms to obtain (we use x(kT) = x(k))

u(k) =
KP + KIT +

KD
T
x(k) − KDTx(k − 1) + KI u(k − 1)

The previous derivation was retrieved from a textbook. 1 However, the used difference equation is shown below. The gains are a substitution. If desired, look up for their definitions in the project’s specifications.

∆u = K0e(kT) + K1e[(k − 1)T] + K2e[(k − 2)T]

1Modern Control Systems by Dorf and Bishop

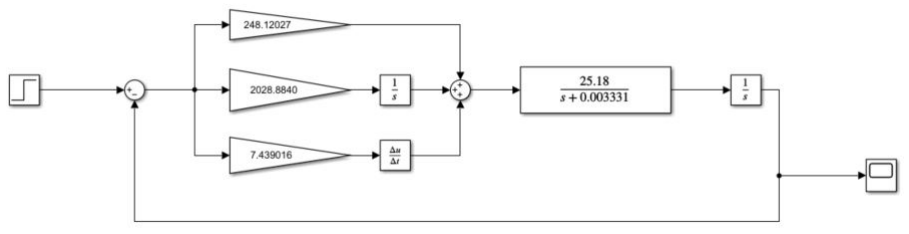
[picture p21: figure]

Figure: Block diagram

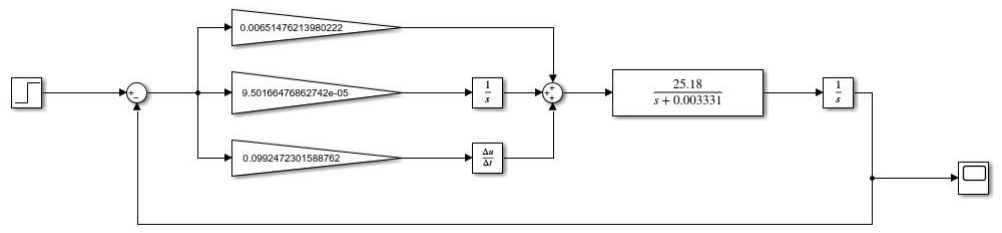
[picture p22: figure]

Figure: Block diagram slower

void PositionMotorControl::controlPID()
{
error = targetPosition -
(currentPosition * 2 * 3.1416 / 493.9); errores[1] = errores[0];
errores[2] = errores[1];
errores[0] = error;
prevPwm = motorSpeed;

double kp = 248;
double ki = 2300;
double kd = 7.44;
double a = (kp + kd/0.02)*errores[0];
double b = (-kp + (ki*0.02) - (2*kd/0.02))*errores[1]; double c = (kd/0.02) * errores[2];

int pwmSpeed = prevPwm + a + b + c;
motorSpeed = pwmSpeed;

if (error <= -1) {
motorDirection = 1;
}
else if (error >= 1) {
motorDirection = -1;
}
else {
motorDirection = 0;
pwmSpeed = 0;
}

## Results of The Control

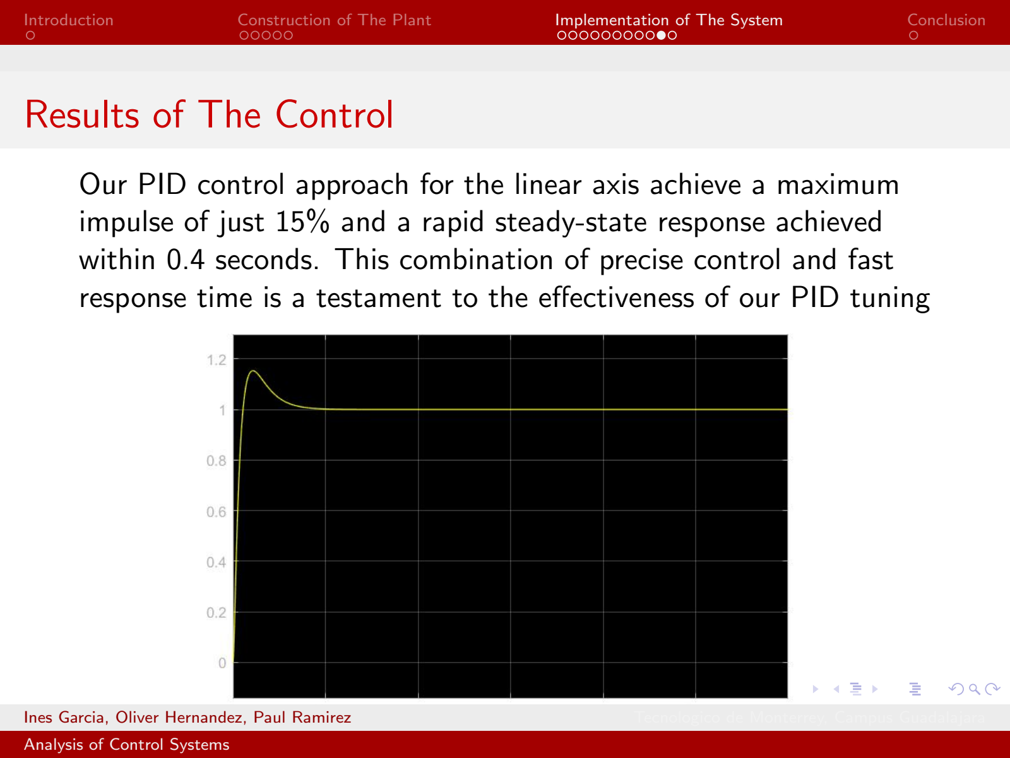
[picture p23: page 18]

Our PID control approach for the linear axis achieve a maximum impulse of just 15% and a rapid steady-state response achieved within 0.4 seconds. This combination of precise control and fast response time is a testament to the effectiveness of our PID tuning

Another aproach with a maximum impulse of 1% and a slower steady-state response achieved within 4 seconds.

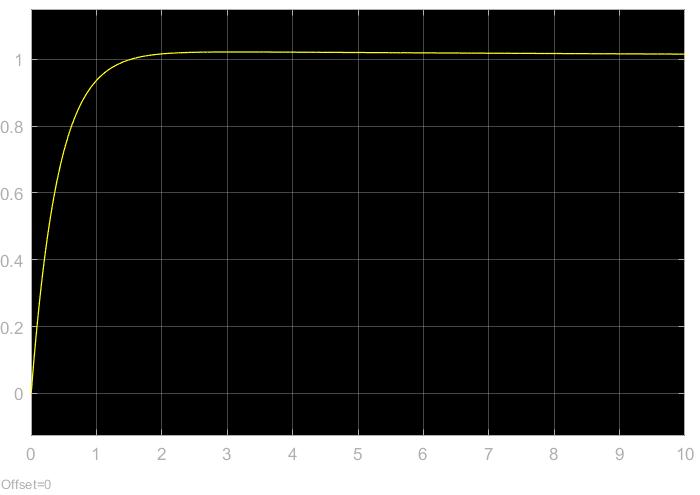
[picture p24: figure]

Ines Garcia, Oliver Hernandez, Paul Ramirez Figure: Response of the PID Control System Tecnologico de Monterrey, Campus Guadalajara

In conclusion, our project’s success can be attributed to the synergy of mechanical, electrical, and software elements working together seamlessly. We’ve designed and constructed a precise linear axis control system that meets our specific requirements. We’ve developed a custom software solution using the ‘PositionMotorControl‘ library, which enables us to achieve accurate control and position feedback. This software, along with our tailored electronics and mechanical components, brings us closer to our project objectives.
For a more detailed look at our project, including the code, hardware specifications, and documentation, please visit our project repository on GitHub:

https://github.com/Ineso1/Linear-Axis-Control

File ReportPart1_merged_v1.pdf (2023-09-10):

1

Report

Inés Alejandro García Mosqueda A00834571

Oliver Josel Hernández Rebollar A01641922

Paul Enrique Alonso Ramírez A01634608

Analysis of Control Systems

Group 401

Tecnológico de Monterrey, Campus Guadalajara

September 9, 2023

2

Report

Computer Numerical Control is a way to instruct manufacturing machinery with a

computer. It is a method widely used in the operation of industrial robots. Commonly, the

instructions for the machinery will come from software known as computer-aided design. One

basic type of CNC is point-to-point. Here the tool executes a set of primitive instructions such as

carving a path given its initial and final point. Memory is required to keep track of the performed

commands (Britannica, 2023).

Linear actuators provide, as the name suggests, motion in a straight line. There are

several ways in which one can achieve linear motion. However, we shall devote our attention to

the conversion from rotary motion to linear motion. A way to achieve this is by using screw

threads to a rotary motion source. The present project utilizes a lead screw. A lead screw has

helical threads that are designed for minimum backlash to allow precise positioning. The rotary

motion of the lead screw is translated into the nut’s linear motion. The torque required to move

the nut will largely depend on the nature of the application (Figliola & Beasley, 2011). The

following image better depicts the given description.

Theoretical Framework

As mentioned, lead screws are a way to transmit power in modern machines. They can

generate high forces with a small moment. Also, they are known for providing a really good level

of motion precision. Thus, we see them extensively in applications that use linear actuators or

3

linear stages. Typically lead screws can operate in two different ways. The first one is by

supplying power to the nut and the other one is by rotating the shaft. Thereby, transferring

power to the nut. In our project, the second way was used in the project. In other words, the

nut’s rotational motion is restricted and the screw shaft rotates. As a consequence the nut

moves along the screw axis, namely, converting the rotary motion into linear motion. There are a

few advantages of lead screws worth noting. Overall, they are cheap and reliable as their

construction is simple; they require little to no maintenance; operations are smooth and reliable;

load capacity is high (Slid, 2022).

H-bridge is a special circuit configuration that allows control over the current source to a

load. This is specially important in motor applications because it is possible to change the

behavior of the motor with an H-bridge. One must be careful always guaranteeing the correct

H-bridge configurations because it is possible to cause a short circuit and damage the

component (Franz, 2023). Operation in an H-Bridge is with switches. When using H-Bridge, one

must consider at all times the switches characteristics and the thermal management of the

circuit. Ignoring these properties can lead to operation failure. As mentioned, H-Bridges are

heavily utilized in motor applications, since they can be mixed with the Pulse Width Modulation,

hence, controlling the motor’s speed (Electricity - Magnetism, n.d.).

An encoder is a sensor that retrieves physical variables. As with almost every known

sensor, encoders convert what they sense into an electrical signal that can later be processed

and handled by a piece of software. These devices help to determine the position, speed and

direction. This is achieved by a count that the encoder generates and sends it to a controller.

There are several technologies that an encoder can use to create a signal; for example,

mechanical, magnetic, resistive and optical. Optical is the most common way. Specifically, The

light emitted from a source is periodically interrupted by a disk with holes. These interruptions

are the ones we use to generate the pulses and then know things like the direction of the

encoder, speed, among others (Encoder Products Company, n.d.).

4

Mechanics

The linear shaft is a long rod-shaped tool used to support linear motion, especially sliding

motion. Without it, we wouldn't complete a sliding mechanism with linear power transmission.

However, manufacturing and selecting the right linear shaft can be complicated. Linear shafts

can have different structures and be made from various materials, depending on the required

properties. With a linear shaft, motion can be guided and adjusted.

The load and specific requirements determine the size and precision of the linear shaft. In linear

power transmission mechanisms, the shaft works alongside an actuator, a support rail, bushings

(ball bearings), etc. In linear power transmission, the actuator typically does all the sliding work,

while the rail, bushings, and linear shafts provide support.

The screw rotates clockwise, causing the shaft, which is essentially a nut on the screw, to move

up and down the screw as the screw rotates. This is what converts the rotational motion of the

electric motor into linear motion. Linear motors have been designed to produce high force at low

speeds and even when stationary. Their design is not based on power but purely on force.

The direct current motor, also known as the direct current motor, is designed to transform

electrical energy into mechanical energy, causing rotary motion. This is made possible thanks to

the magnetic field that composes it, which is perhaps the most important part of the whole

equipment. However, it requires other components to operate effectively, such as the stator,

which serves as mechanical support for the device and holds the machine's poles, which can be

wound with copper wire around an iron core or permanent magnets. The rotor is a cylindrical

instrument with a winding and a core, which are supplied with direct current through the

collector formed by commutator segments. The commutator segments are made of copper and

are in contact with the fixed brushes.

There are two ways to mount the linear shaft: continuous support and end support. Continuous

support shafts are generally used for heavier loads, while those supported at both ends are

used for lighter loads.

5


Electronics

In the realm of the Linear Axis, where precision is paramount, our electronic components serve

as the central nervous system, orchestrating every facet of movement and control. This

electronic symphony relies on a harmonious ensemble of key components, each playing a

unique and indispensable role.

The L298N motor driver plays a critical role in our Linear Axis Control Project, serving as the

primary component to translate electronic signals into precise physical motion. This integrated

circuit, known for its versatility and reliability, acts as the conductor for the motor's performance.

The main function of the L298N motor driver is essential to our system, serving three main

functions:

- Direction Control: The motor driver manages the motor's direction by reversing the

polarity of the applied voltage to achieve forward or reverse motion.

- Speed Regulation: It allows us to adjust the motor's speed by varying the supplied

voltage, providing us with the capability for precise speed control.

- Current Management: It incorporates current-sensing circuits to prevent overcurrent

conditions, protecting both the motor and the driver itself.

6

At the core of our project's electronics is the Arduino Mega, a microcontroller board based on

the ATmega2560. This microcontroller serves as the project's central processing unit, executing

complex control algorithms and facilitating seamless communication with various sensors and

components. The choice of Arduino Mega contributes to the project's user-friendliness and

versatility, making it an ideal candidate for orchestrating the multi-disciplinary aspects of our

linear axis control system.


The motor-reducer assembly seamlessly integrates a motor, reduction gearbox, and encoder, a

trio of components that harmonize to deliver precise control over the linear motion of our axis. At

the core of this assembly is the motor, strategically coupled with a reduction gearbox. Together,

they form a symbiotic relationship, with the motor providing the mechanical power required to

propel the linear motion. The reduction gearbox, with an approximate reduction ratio of 1:45,

transforms the motor's high-speed rotation into the slower, high-torque movement essential for

7

our project's precision. Nestled within this assembly is the encoder, a sentinel of precision. This

vital component employs Hall Effect technology and boasts a resolution of approximately 493.9

PPR (Pulses Per Revolution) with a ±10% tolerance. Operating within a voltage range of 3.3V to

5V and offering a response frequency of 100 kHz, the encoder delivers real-time feedback that

is instrumental in our pursuit of accuracy. The motor, reduction gearbox, and encoder operate in

tandem to orchestrate the linear motion of our axis. As the motor churns, the gearbox tempers

its high-speed rotation, allowing for controlled movement. Simultaneously, the encoder diligently

records every aspect of this motion—position, speed, and direction. This trove of data serves as

the compass by which our system navigates, ensuring that the linear axis moves precisely as

intended.


Standard Wiring Configuration for L298N

8

In the context of connecting and utilizing the L298N motor driver, a typical wiring configuration is

employed to ensure optimal functionality. This standard connection scheme serves as the

foundation for effectively controlling motors and is widely adopted in various applications.

Software

The software we developed is quite simple because we were instructed to use an

Arduino which is known for being user friendly. We wanted to increase the portability and

robustness of our design, so we implemented a class called PositionMotorControl. This class

has five methods for orchestrating the motor’s behavior. The constructor will retrieve all the

information for the member functions. Initialization method will send the constructor’s data to the

Arduino. Control method will be rotating the shaft based upon an error computed using the

number of pulses. Set Target Position receives the desired position in the number of pulses. Get

Current Position returns the current position attribute and Set Cero establishes what will be

taken as the reference, namely, the origin. Attributes declared with the volatile qualifier are used

in the interruption called Handle Encoder. This private function member reads the encoder in

real time and updates things like current position and the motor’s direction. It is declared as

9

static and thus uses a pointer to be called. At the beginning of the main program we create a

motor instance, then set the baud rate to communicate with the microcontroller. Lastly we enter

the loop and read the Serial Monitor to receive input from the user, if that does not happen, we

print the position. Later the control method is called and moves the nut to the desired position.

The following is a high-level description of the main program.


10

https://uelectronics.com/producto/gm-25-370-motor-con-encoder-12v-dc-140rpm-330rpm/

https://uelectronics.com/producto/balero-rodamiento-lineal-lm8uu-de-8mm-3d-cnc/

11

Cople Flexible D18L25 Nema Acoplador

Etiquetas: Acoplador Nema, (https://uelectronics.com/etiqueta-producto/acoplador-nema/) cople, (https://uelectronics.com/etiqueta-producto/cople/) Cople D18L25, (https://uelectronics.com/etiqueta-producto/cople-d18l25/) cople flexible, (https://uelectronics.com/etiqueta-producto/cople-flexible/) Cople Flexible 5x5mm, (https://uelectronics.com/etiqueta-producto/cople-flexible-5x5mm/) Cople Flexible 5x8mm, (https://uelectronics.com/etiqueta-producto/cople-flexible-5x8mm/)

Cople Flexible 6.35x8mm, (https://uelectronics.com/etiqueta-producto/cople-flexible-6-35x8mm/) Cople Flexible 8x10mm, (https://uelectronics.com/etiqueta-producto/cople-flexible-8x10mm/) Cople Flexible 8x8mm, (https://uelectronics.com/etiqueta-producto/cople-flexible-8x8mm/) Cople Flexible D18L25, (https://uelectronics.com/etiqueta-producto/cople-flexible-d18l25/) D18L25, (https://uelectronics.com/etiqueta-producto/d18l25/) Piezas y

Accesorios 3D CNC (https://uelectronics.com/etiqueta-producto/piezas-y-accesorios-3d-cnc/)

https://uelectronics.com/producto/cople-flexible-d18l25-nema-acoplador/

Varilla Lisa 8mm


Varilla Lisa 8mm 60cm para Impresora 3D/CNC

https://uelectronics.com/producto/varilla-lisa-8mm-para-impresora-3d-cnc/


F Dept. Technical reference Created by Approved by Document type Document status Title DWG No. Rev. Date of issue Sheet 25/08/2023 25/08/2023 1/1 Ines G., Oliver H., Paul A. Chasis Eje Lineal R2

# 18 ²⁴ 35 R5 R2

18 R8 R11


1 A 2 3 4 5 6 7 8 1 2 3 4 5 6 7 8 BCDEF ABCDEF Dept. Technical reference Created by Approved by Document type Document status Title DWG No. Rev. Date of issue Sheet 25/08/2023 25/08/2023 1/1 Ines G., Oliver H., Paul A. Camisas ELienales Ø15 34

12

References

Britannica. (2023, May 28). Computer Numerical Control.

https://www.britannica.com/technology/numerical-control

Electricity - Magnetism. (n.d.). H-Bridges. https://www.electricity-magnetism.org/h-bridges/

Encoder Products Company. (n.d.). What is an encoder?.

https://www.encoder.com/article-what-is-an-encoder

Figliola, R., & Beasley, D. (2011). Theory and Design for Mechanical Measurements. John Wiley

& Sons, Inc.

Franz, K. (2023, April 18). What Is an H-Bridge?. https://digilent.com/blog/what-is-an-h-bridge/

Slid Siim. (2022, January 24). Lead Screws Explained. https://fractory.com/lead-screws/

Mega, A. (s/f). Arduino® MEGA 2560 Rev3. Arduino.cc. Recuperado el 10 de septiembre de

2023, de https://docs.arduino.cc/resources/datasheets/A000067-datasheet.pdf

Mega, A. (s/f). Arduino® MEGA 2560 Rev3. Arduino.cc. Recuperado el 10 de septiembre de

2023, de https://docs.arduino.cc/resources/datasheets/A000067-datasheet.pdf

Mega, A. (s/f). Arduino® MEGA 2560 Rev3. Arduino.cc. Recuperado el 10 de septiembre de

2023, de https://docs.arduino.cc/resources/datasheets/A000067-datasheet.pdf

Appendix

The code for the axis can be found here

https://github.com/Ineso1/Linear-Axis-Control/tree/main/ControlProgram/LinearAxisControl_v1

## Arduino® MEGA 2560 Rev3

1 / 18 | Arduino® MEGA 2560 Rev3 | Modified: 06/09/2023

Product Reference Manual
SKU: A000067

## Description

Arduino® Mega 2560 is an exemplary development board dedicated for building extensive applications as compared to other maker boards by Arduino. The board accommodates the ATmega2560 microcontroller, which operates at a frequency of 16 MHz. The board contains 54 digital input/output pins, 16 analog inputs, 4 UARTs (hardware serial ports), a USB connection, a power jack, an ICSP header, and a reset button.

## Target Areas

3D Printing, Robotics, Maker

2 / 18 | Arduino® MEGA 2560 Rev3 | Modified: 06/09/2023

## Features

ATmega2560 Processor
Up to 16 MIPS Throughput at 16MHz
256k bytes (of which 8k is used for the bootloader) 4k bytes EEPROM
8k bytes Internal SRAM
32 × 8 General Purpose Working Registers
Real Time Counter with Separate Oscillator Four 8-bit PWM Channels
Four Programmable Serial USART Controller/Peripheral SPI Serial Interface

ATmega16U2
Up to 16 MIPS Throughput at 16 MHz 16k bytes ISP Flash Memory
512 bytes EEPROM
512 bytes SRAM
USART with SPI master only mode and hardware flow control (RTS/CTS) Master/Slave SPI Serial Interface

Sleep Modes
Idle
ADC Noise Reduction
Power-save
Power-down
Standby
Extended Standby

Power
USB Connection
External AC/DC Adapter

I/O
54 Digital
16 Analog
15 PWM Output

3 / 18 | Arduino® MEGA 2560 Rev3 | Modified: 06/09/2023

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
# Contents

### 1 The Board

1.1 Application Examples
1.2 Accessories
1.3 Related Products

### 2 Ratings

2.1 Recommended Operating Conditions 2.2 Power Consumption

### 3 Functional Overview

3.1 Block Diagram
3.2 Board Topology
3.3 Processor
3.4 Power Tree

### 4 Board Operation

4.1 Getting Started - IDE
4.2 Getting Started - Arduino Web Editor 4.3 Sample Sketches
4.4 Online Resources

### 5 Connector Pinouts

5.1 Analog
5.2 Digital
5.3 ATMEGA16U2 JP5
5.4 ATMEGA16U2 ICSP1
5.5 Digital Pins D22 - D53 LHS 5.6 Digital Pins D22 - D53 RHS

### 6 Mechanical Information

6.1 Board Outline
6.2 Board Mount Holes

### 7 Declaration of Conformity CE DoC (EU) 8 Declaration of Conformity to EU RoHS & REACH 211 01/19/2021 9 Conflict Minerals Declaration 10 FCC Caution 11 Company Information 12 Reference Documentation

4 / 18 | Arduino® MEGA 2560 Rev3 | Modified: 06/09/2023
13 Revision History | 18

5 / 18 | Arduino® MEGA 2560 Rev3 | Modified: 06/09/2023

## 1 The Board

Arduino® Mega 2560 is a successor board of Arduino Mega, it is dedicated to applications and projects that require large number of input output pins and the use cases which need high processing power. The Arduino® Mega 2560 comes with a much larger set of IOs when we compare it with traditional Uno board considering the form factor of both the boards.

### 1.1 Application Examples

Robotics: Featuring the high processing capacitity, the Arduino Mega 2560 can handle the extensive robotic applications. It is compatible with the motor controller shield that enables it to control multiple motors at an instance, thus making it perfect of robotic applications. The large number of I/O pins can accommodate many robotic sensors as well.

3D Printing: Algorithms play a significant role in implementation of 3D printers. Arduino Mega 2560 has the power to process these complex algorithms required for 3D printing. Additionally, the slight changes to the code is easily possible with the Arduino IDE and thus 3D printing programs can be customized according to user requirements.
Wi-Fi: Integrating wireless functionality enhances the utility of the applications. Arduino Mega 2560 is compatible with WiFi shields hence allowing the wireless features for the applications in 3D printing and Robotics.

### 1.2 Accessories

### 1.3 Related Products

Arduino® Uno Rev 3
Arduino® Nano
Arduino® DUE without headers

6 / 18 | Arduino® MEGA 2560 Rev3 | Modified: 06/09/2023

## 2 Ratings

### 2.1 Recommended Operating Conditions

Symbol | Description | Min | Max
TOP | Operating temperature: | -40 °C | 85 °C

### 2.2 Power Consumption

Symbol | Description | Min | Typ | Max | Unit
PWRIN | Input supply from power jack | | TBC | | mW
USB VCC | Input supply from USB | | TBC | | mW
VIN | Input from VIN pad | | TBC | | mW

## 3 Functional Overview

### 3.1 Block Diagram

Arduino MEGA Block Diagram


Arduino MEGA Top View

Ref. | Description | Ref. | Description
USB | USB B Connector | F1 | Chip Capacitor
IC1 | 5V Linear Regulator | X1 | Power Jack Connector
JP5 | Plated Holes | IC4 | ATmega16U2 chip
PC1 | Electrolytic Alumninum Capacitor | PC2 | Electrolytic Alumninum Capacitor
D1 | General Purpose Rectifier | D3 | General Purpose Diode
L2 | Fixed Inductor | IC3 | ATmega2560 chip
ICSP | Connector Header | ON | Green LED
RN1 | Resistor Array | XIO | Connector

3.4 Power Tree; Power Tree

8 / 18 | Arduino® MEGA 2560 Rev3 | Modified: 06/09/2023

### 3.3 Processor

Primary processor of Arduino Mega 2560 Rev3 board is ATmega2560 chip which operates at a frequency of 16 MHz. It accommodates a large number of input and output lines which gives the provision of interfacing many external devices. At the same time the operations and processing is not slowed due to its significantly larger RAM than the other processors. The board also features a USB serial processor ATmega16U2 which acts an interface between the USB input signals and the main processor. This increases the flexibility of interfacing and connecting peripherals to the Arduino Mega 2560 Rev 3 board.

9 / 18 | Arduino® MEGA 2560 Rev3 | Modified: 06/09/2023

## 4 Board Operation

### 4.1 Getting Started - IDE

If you want to program your Arduino® MEGA 2560 while offline you need to install the Arduino® Desktop IDE [1] To connect the Arduino® MEGA 2560 to your computer, you’ll need a Type-B USB cable. This also provides power to the board, as indicated by the LED.

### 4.2 Getting Started - Arduino Web Editor

All Arduino® boards, including this one, work out-of-the-box on the Arduino® Web Editor [2], by just installing a simple plugin.

The Arduino® Web Editor is hosted online, therefore it will always be up-to-date with the latest features and support for all boards. Follow [3] to start coding on the browser and upload your sketches onto your board.

### 4.3 Sample Sketches

Sample sketches for the Arduino® MEGA 2560 can be found either in the “Examples” menu in the Arduino® IDE

### 4.4 Online Resources

Now that you have gone through the basics of what you can do with the board you can explore the endless possibilities it provides by checking exciting projects on ProjectHub [5], the Arduino® Library Reference [6] and the online store [7] where you will be able to complement your board with sensors, actuators and more.

10 / 18 | Arduino® MEGA 2560 Rev3 | Modified: 06/09/2023

## 5 Connector Pinouts

Arduino Mega Pinout

11 / 18 | Arduino® MEGA 2560 Rev3 | Modified: 06/09/2023

### 5.1 Analog

Pin | Function | Type | Description
1 | NC | NC | Not Connected
2 | IOREF | IOREF | Reference for digital logic V - connected to 5V
3 | Reset | Reset | Reset
4 | +3V3 | Power | +3V3 Power Rail
5 | +5V | Power | +5V Power Rail
6 | GND | Power | Ground
7 | GND | Power | Ground
8 | VIN | Power | Voltage Input
9 | A0 | Analog | Analog input 0 /GPIO
10 | A1 | Analog | Analog input 1 /GPIO
11 | A2 | Analog | Analog input 2 /GPIO
12 | A3 | Analog | Analog input 3 /GPIO
13 | A4 | Analog | Analog input 4 /GPIO
14 | A5 | Analog | Analog input 5 /GPIO
15 | A6 | Analog | Analog input 6 /GPIO
16 | A7 | Analog | Analog input 7 /GPIO
17 | A8 | Analog | Analog input 8 /GPIO
18 | A9 | Analog | Analog input 9 /GPIO
19 | A10 | Analog | Analog input 10 /GPIO
20 | A11 | Analog | Analog input 11 /GPIO
21 | A12 | Analog | Analog input 12 /GPIO
22 | A13 | Analog | Analog input 13 /GPIO
23 | A14 | Analog | Analog input 14 /GPIO
24 | A15 | Analog | Analog input 15 /GPIO

### 5.2 Digital

Pin | Function | Type | Description
1 | D21/SCL | Digital Input/I2C | Digital input 21/I2C Dataline
2 | D20/SDA | Digital Input/I2C | Digital input 20/I2C Dataline
3 | AREF | Digital | Analog Reference Voltage
4 | GND | Power | Ground
5 | D13 | Digital/GPIO | Digital input 13/GPIO
6 | D12 | Digital/GPIO | Digital input 12/GPIO
7 | D11 | Digital/GPIO | Digital input 11/GPIO
8 | D10 | Digital/GPIO | Digital input 10/GPIO
9 | D9 | Digital/GPIO | Digital input 9/GPIO
10 | D8 | Digital/GPIO | Digital input 8/GPIO
11 | D7 | Digital/GPIO | Digital input 7/GPIO
12 | D6 | Digital/GPIO | Digital input 6/GPIO
13 | D5 | Digital/GPIO | Digital input 5/GPIO
14 | D4 | Digital/GPIO | Digital input 4/GPIO


Pin | Function | Type | Description
15 | D3 | Digital/GPIO | Digital input 3/GPIO
16 | D2 | Digital/GPIO | Digital input 2/GPIO
17 | D1/TX0 | Digital/GPIO | Digital input 1 /GPIO
18 | D0/Tx1 | Digital/GPIO | Digital input 0 /GPIO
19 | D14 | Digital/GPIO | Digital input 14 /GPIO
20 | D15 | Digital/GPIO | Digital input 15 /GPIO
21 | D16 | Digital/GPIO | Digital input 16 /GPIO
22 | D17 | Digital/GPIO | Digital input 17 /GPIO
23 | D18 | Digital/GPIO | Digital input 18 /GPIO
24 | D19 | Digital/GPIO | Digital input 19 /GPIO
25 | D20 | Digital/GPIO | Digital input 20 /GPIO
26 | D21 | Digital/GPIO | Digital input 21 /GPIO

13 / 18 | Arduino® MEGA 2560 Rev3 | Modified: 06/09/2023

### 5.3 ATMEGA16U2 JP5

Pin | Function | Type | Description
1 | PB4 | Internal | Serial Wire Debug
2 | PB6 | Internal | Serial Wire Debug
3 | PB5 | Internal | Serial Wire Debug
4 | PB7 | Internal | Serial Wire Debug

### 5.4 ATMEGA16U2 ICSP1

Pin | Function | Type | Description
1 | CIPO | Internal | Controller In Peripheral Out
2 | +5V | Internal | Power Supply of 5V
3 | SCK | Internal | Serial Clock
4 | COPI | Internal | Controller Out Peripheral In
5 | RESET | Internal | Reset
6 | GND | Internal | Ground

### 5.5 Digital Pins D22 - D53 LHS

Pin | Function | Type | Description
1 | +5V | Power | Power Supply of 5V
2 | D22 | Digital | Digital input 22/GPIO
3 | D24 | Digital | Digital input 24/GPIO
4 | D26 | Digital | Digital input 26/GPIO
5 | D28 | Digital | Digital input 28/GPIO
6 | D30 | Digital | Digital input 30/GPIO
7 | D32 | Digital | Digital input 32/GPIO
8 | D34 | Digital | Digital input 34/GPIO
9 | D36 | Digital | Digital input 36/GPIO
10 | D38 | Digital | Digital input 38/GPIO
11 | D40 | Digital | Digital input 40/GPIO
12 | D42 | Digital | Digital input 42/GPIO
13 | D44 | Digital | Digital input 44/GPIO
14 | D46 | Digital | Digital input 46/GPIO
15 | D48 | Digital | Digital input 48/GPIO
16 | D50 | Digital | Digital input 50/GPIO
17 | D52 | Digital | Digital input 52/GPIO
18 | GND | Power | Ground


Pin | Function | Type | Description
1 | +5V | Power | Power Supply of 5V
2 | D23 | Digital | Digital input 23/GPIO
3 | D25 | Digital | Digital input 25/GPIO
4 | D27 | Digital | Digital input 27/GPIO
5 | D29 | Digital | Digital input 29/GPIO
6 | D31 | Digital | Digital input 31/GPIO
7 | D33 | Digital | Digital input 33/GPIO
8 | D35 | Digital | Digital input 35/GPIO
9 | D37 | Digital | Digital input 37/GPIO
10 | D39 | Digital | Digital input 39/GPIO
11 | D41 | Digital | Digital input 41/GPIO
12 | D43 | Digital | Digital input 43/GPIO
13 | D45 | Digital | Digital input 45/GPIO
14 | D47 | Digital | Digital input 47/GPIO
15 | D49 | Digital | Digital input 49/GPIO
16 | D51 | Digital | Digital input 51/GPIO
17 | D53 | Digital | Digital input 53/GPIO
18 | GND | Power | Ground


15 / 18 | Arduino® MEGA 2560 Rev3 | Modified: 06/09/2023

Arduino Mega Outline

### 6.2 Board Mount Holes

Arduino Mega Mount Holes

# Certifications

## 7 Declaration of Conformity CE DoC (EU)

We declare under our sole responsibility that the products above are in conformity with the essential requirements of the following EU Directives and therefore qualify for free movement within markets comprising the European Union (EU) and European Economic Area (EEA).

16 / 18 | Arduino® MEGA 2560 Rev3 | Modified: 06/09/2023

## 8 Declaration of Conformity to EU RoHS & REACH 211

01/19/2021

Arduino boards are in compliance with RoHS 2 Directive 2011/65/EU of the European Parliament and RoHS 3 Directive 2015/863/EU of the Council of 4 June 2015 on the restriction of the use of certain hazardous substances in electrical and electronic equipment.

Substance | Maximum Limit (ppm)
Lead (Pb) | 1000
Cadmium (Cd) | 100
Mercury (Hg) | 1000
Hexavalent Chromium (Cr6+) | 1000
Poly Brominated Biphenyls (PBB) | 1000
Poly Brominated Diphenyl ethers (PBDE) | 1000
Bis(2-Ethylhexyl} phthalate (DEHP) | 1000
Benzyl butyl phthalate (BBP) | 1000
Dibutyl phthalate (DBP) | 1000
Diisobutyl phthalate (DIBP) | 1000

Exemptions : No exemptions are claimed.

Arduino Boards are fully compliant with the related requirements of European Union Regulation (EC) 1907 /2006 concerning the Registration, Evaluation, Authorization and Restriction of Chemicals (REACH). We declare none of the SVHCs (https://echa.europa.eu/web/guest/candidate-list-table), the Candidate List of Substances of Very High Concern for authorization currently released by ECHA, is present in all products (and also package) in quantities totaling in a concentration equal or above 0.1%. To the best of our knowledge, we also declare that our products do not contain any of the substances listed on the "Authorization List" (Annex XIV of the REACH regulations) and Substances of Very High Concern (SVHC) in any significant amounts as specified by the Annex XVII of Candidate list published by ECHA (European Chemical Agency) 1907 /2006/EC.

17 / 18 | Arduino® MEGA 2560 Rev3 | Modified: 06/09/2023

## 9 Conflict Minerals Declaration

As a global supplier of electronic and electrical components, Arduino is aware of our obligations with regards to laws and regulations regarding Conflict Minerals, specifically the Dodd-Frank Wall Street Reform and Consumer Protection Act, Section 1502. Arduino does not directly source or process conflict minerals such as Tin, Tantalum, Tungsten, or Gold. Conflict minerals are contained in our products in the form of solder, or as a component in metal alloys. As part of our reasonable due diligence Arduino has contacted component suppliers within our supply chain to verify their continued compliance with the regulations. Based on the information received thus far we declare that our products contain Conflict Minerals sourced from conflict-free areas.

## 10 FCC Caution

Any Changes or modifications not expressly approved by the party responsible for compliance could void the user’s authority to operate the equipment.

This device complies with part 15 of the FCC Rules. Operation is subject to the following two conditions:

(1) This device may not cause harmful interference
(2) this device must accept any interference received, including interference that may cause undesired operation.

FCC RF Radiation Exposure Statement:

1. This Transmitter must not be co-located or operating in conjunction with any other antenna or transmitter.
2. This equipment complies with RF radiation exposure limits set forth for an uncontrolled environment.
3. This equipment should be installed and operated with minimum distance 20cm between the radiator & your body.

English: User manuals for licence-exempt radio apparatus shall contain the following or equivalent notice in a conspicuous location in the user manual or alternatively on the device or both. This device complies with Industry Canada licence-exempt RSS standard(s). Operation is subject to the following two conditions:

(1) this device may not cause interference
(2) this device must accept any interference, including interference that may cause undesired operation of the device.

French: Le présent appareil est conforme aux CNR d’Industrie Canada applicables aux appareils radio exempts de licence. L’exploitation est autorisée aux deux conditions suivantes :

(1) l’ appareil nedoit pas produire de brouillage
(2) l’utilisateur de l’appareil doit accepter tout brouillage radioélectrique subi, même si le brouillage est susceptible d’en compromettre le fonctionnement.

IC SAR Warning:

English This equipment should be installed and operated with minimum distance 20 cm between the radiator and your body.

18 / 18 | Arduino® MEGA 2560 Rev3 | Modified: 06/09/2023

French: Lors de l’ installation et de l’ exploitation de ce dispositif, la distance entre le radiateur et le corps est d ’au moins 20 cm.
Important: The operating temperature of the EUT can’t exceed 85℃ and shouldn’t be lower than -40℃.

Hereby, Arduino S.r.l. declares that this product is in compliance with essential requirements and other relevant provisions of Directive 201453/EU. This product is allowed to be used in all EU member states.

## 11 Company Information

Company name | Arduino S.r.l.
Company Address | Arduino SRL, Via Andrea Appiani 25, 20900 Monza MB, Italy

## 12 Reference Documentation

Ref | Link
Arduino IDE (Desktop) | https://www.arduino.cc/en/Main/Software
Arduino IDE (Cloud) | https://create.arduino.cc/editor
Cloud IDE Getting Started | https://create.arduino.cc/projecthub/Arduino_Genuino/getting-started-with-arduino-web-editor-4b3e4a (https://create.arduino.cc/projecthub/Arduino_Genuino/getting-started-with-arduino-web-editor-4b3e4a)
Arduino Pro Website | https://www.arduino.cc/pro
Project Hub | https://create.arduino.cc/projecthub?by=part&part_id=11332&sort=trending
Library Reference | https://www.arduino.cc/reference/en/libraries/
Online Store | https://store.arduino.cc/

## 13 Revision History

Date | Revision | Changes
29/09/2020 | 1 | First Release

L298

## DUAL FULL-BRIDGE DRIVER

ORDERING NUMBERS : L298N (Multiwatt Vert.)

. OPERATING SUPPLY VOLTAGE UP TO 46 V . TOTAL DC CURRENT UP TO 4 A
. LOW SATURATION VOLTAGE
. OVERTEMPERATURE PROTECTION
. LOGICAL "0" INPUT VOLTAGE UP TO 1.5 V

(HIGH NOISE IMMUNITY)

DESCRIPTION
The L298 is an integrated monolithic circuit in a 15-lead Multiwatt and PowerSO20 packages. It is a high voltage, high current dual full-bridge driver designed to accept standard TTL logic levels and drive inductive loads such as relays, solenoids, DC and stepping motors. Two enable inputs are provided to enable or disable the device independently of the input signals. The emitters of the lower transistors of each bridge are connected together and the corre-

Jenuary 2000; BLOCK DIAGRAM; lower voltage.

sponding external terminal can be used for the connection of an external sensing resistor. An additional supply input is provided so that the logic works at a

®

ABSOLUTE MAXIMUM RATINGS

Symbol | Parameter | Value | Unit
VS | Power Supply | 50 | V
VSS | Logic Supply Voltage | 7 | V
VI,Ven | Input and Enable Voltage | –0.3 to 7 | V
IO | Peak Output Current (each Channel) – Non Repetitive (t = 100µs) –Repetitive (80% on –20% off; ton = 10ms) –DC Operation | 3 2.5 2 | A A A
Vsens | Sensing Voltage | –1 to 2.3 | V
Ptot | Total Power Dissipation (Tcase = 75°C) | 25 | W

PIN CONNECTIONS (top view); GND; Input 2; VSS; Out 1; Out 2; Input 1; Enable A; Sense A; Input 3; Enable B; Out 3; Input 4; Out 4; Sense B; Top; Junction Operating Temperature; Tstg, Tj; Storage and Junction Temperature; THERMAL DATA; Symbol; Parameter; PowerSO20; Multiwatt15; Unit; Rth j-case; Thermal Resistance Junction-case Max.; ENABLE B INPUT 3 LOGIC SUPPLY VOLTAGE VSS GND INPUT 2 ENABLE A INPUT 1 SUPPLY VOLTAGE VS OUTPUT 2 OUTPUT 1 CURRENT SENSING A; TAB CONNECTED TO PIN 8; CURRENT SENSING B OUTPUT 4 OUTPUT 3 INPUT 4

Rth j-amb | Thermal Resistance Junction-ambient Max. | 13 (*) | 35 | °C/W

(*) Mounted on aluminum substrate

L298

2/13

PIN FUNCTIONS (refer to the block diagram)

MW.15 | PowerSO | Name | Function
1;15 | 2;19 | Sense A; Sense B | Between this pin and ground is connected the sense resistor to control the current of the load.
2;3 | 4;5 | Out 1; Out 2 | Outputs of the Bridge A; the current that flows through the load connected between these two pins is monitored at pin 1.
4 | 6 | VS | Supply Voltage for the Power Output Stages. A non-inductive 100nF capacitor must be connected between this pin and ground.
5;7 | 7;9 | Input 1; Input 2 | TTL Compatible Inputs of the Bridge A.
6;11 | 8;14 | Enable A; Enable B | TTL Compatible Enable Input: the L state disables the bridge A (enable A) and/or the bridge B (enable B).
8 | 1,10,11,20 | GND | Ground.
9 | 12 | VSS | Supply Voltage for the Logic Blocks. A100nF capacitor must be connected between this pin and ground.
10; 12 | 13;15 | Input 3; Input 4 | TTL Compatible Inputs of the Bridge B.
13; 14 | 16;17 | Out 3; Out 4 | Outputs of the Bridge B. The current that flows through the load connected between these two pins is monitored at pin 15.
– | 3;18 | N.C. | Not Connected

ELECTRICAL CHARACTERISTICS (VS = 42V; VSS = 5V, Tj = 25°C; unless otherwise specified)

Symbol | Parameter | Test Conditions | Min. | Typ. | Max. | Unit
VS | Supply Voltage (pin 4) | Operative Condition | VIH +2.5 | | 46 | V
VSS | Logic Supply Voltage (pin 9) | | 4.5 | 5 | 7 | V
IS | Quiescent Supply Current (pin 4) | Ven = H; IL = 0 Vi = L Vi = H | | 13 50 | 22 70 | mA mA
| | Ven = L Vi = X | | | 4 | mA
ISS | Quiescent Current from VSS (pin 9) | Ven = H; IL = 0 Vi = L Vi = H | | 24 7 | 36 12 | mA mA
| | Ven = L Vi = X | | | 6 | mA
ViL | Input Low Voltage (pins 5, 7, 10, 12) | | –0.3 | | 1.5 | V
ViH | Input High Voltage (pins 5, 7, 10, 12) | | 2.3 | | VSS | V
IiL | Low Voltage Input Current (pins 5, 7, 10, 12) | Vi = L | | | –10 | µA
IiH | High Voltage Input Current (pins 5, 7, 10, 12) | Vi = H ≤ VSS –0.6V | | 30 | 100 | µA
Ven = L | Enable Low Voltage (pins 6, 11) | | –0.3 | | 1.5 | V
Ven = H | Enable High Voltage (pins 6, 11) | | 2.3 | | VSS | V
Ien = L | Low Voltage Enable Current (pins 6, 11) | Ven = L | | | –10 | µA
Ien = H | High Voltage Enable Current (pins 6, 11) | Ven = H ≤ VSS –0.6V | | 30 | 100 | µA
VCEsat (H) | Source Saturation Voltage | IL = 1A IL = 2A | 0.95 | 1.35 2 | 1.7 2.7 | V V
VCEsat (L) | Sink Saturation Voltage | IL = 1A (5) IL = 2A (5) | 0.85 | 1.2 1.7 | 1.6 2.3 | V V
VCEsat | Total Drop | IL = 1A (5) IL = 2A (5) | 1.80 | | 3.2 4.9 | V V
Vsens | Sensing Voltage (pins 1, 15) | | –1 (1) | | 2 | V

L298

3/13

Current.

ELECTRICAL CHARACTERISTICS (continued)

Symbol | Parameter | Test Conditions | Min. | Typ. | Max. | Unit
T1 (Vi) | Source Current Turn-off Delay | 0.5 Vi to 0.9 IL (2); (4) | | 1.5 | | µs
T2 (Vi) | Source Current Fall Time | 0.9 IL to 0.1 IL (2); (4) | | 0.2 | | µs
T3 (Vi) | Source Current Turn-on Delay | 0.5 Vi to 0.1 IL (2); (4) | | 2 | | µs
T4 (Vi) | Source Current Rise Time | 0.1 IL to 0.9 IL (2); (4) | | 0.7 | | µs
T5 (Vi) | Sink Current Turn-off Delay | 0.5 Vi to 0.9 IL (3); (4) | | 0.7 | | µs
T6 (Vi) | Sink Current Fall Time | 0.9 IL to 0.1 IL (3); (4) | | 0.25 | | µs
T7 (Vi) | Sink Current Turn-on Delay | 0.5 Vi to 0.9 IL (3); (4) | | 1.6 | | µs
T8 (Vi) | Sink Current Rise Time | 0.1 IL to 0.9 IL (3); (4) | | 0.2 | | µs
fc (Vi) | Commutation Frequency | IL = 2A | | 25 | 40 | KHz
T1 (Ven) | Source Current Turn-off Delay | 0.5 Ven to 0.9 IL (2); (4) | | 3 | | µs
T2 (Ven) | Source Current Fall Time | 0.9 IL to 0.1 IL (2); (4) | | 1 | | µs
T3 (Ven) | Source Current Turn-on Delay | 0.5 Ven to 0.1 IL (2); (4) | | 0.3 | | µs
T4 (Ven) | Source Current Rise Time | 0.1 IL to 0.9 IL (2); (4) | | 0.4 | | µs
T5 (Ven) | Sink Current Turn-off Delay | 0.5 Ven to 0.9 IL (3); (4) | | 2.2 | | µs
T6 (Ven) | Sink Current Fall Time | 0.9 IL to 0.1 IL (3); (4) | | 0.35 | | µs
T7 (Ven) | Sink Current Turn-on Delay | 0.5 Ven to 0.9 IL (3); (4) | | 0.25 | | µs
T8 (Ven) | Sink Current Rise Time | 0.1 IL to 0.9 IL (3); (4) | | 0.1 | | µs

1) 1)Sensing voltage can be –1 V for t ≤ 50 µsec; in steady state Vsens min ≥ – 0.5 V.
2) See fig. 2.
3) See fig. 4.
4) The load must be a pure resistor.

Figure 1 : Typical Saturation Voltage vs. Output

Figure 2 : Switching Times Test Circuits.

Note : For INPUT Switching, set EN = H
For ENABLE Switching, set IN = H


Figure 3 : Source Current Delay Times vs. Input or Enable Switching.

Figure 4 : Switching Times Test Circuits.

Note : For INPUT Switching, set EN = H
For ENABLE Switching, set IN = L

L = Low; H = High; X = Don’t care

Figure 5 : Sink Current Delay Times vs. Input 0 V Enable Switching.

Figure 6 : Bidirectional DC Motor Control.

Inputs | Function

Ven = H | C = H ; D = L | Forward

C = L ; D = H | Reverse
C = D | Fast Motor Stop

Ven = L | C = X ; D = X | Free Running Motor Stop

Figure 7 : For higher currents, outputs can be paralleled. Take care to parallel channel 1 with channel 4 and channel 2 with channel 3.


APPLICATION INFORMATION (Refer to the block diagram)
1.1. POWER OUTPUT STAGE
The L298 integrates two power output stages (A ; B).
The power output stage is a bridge configuration
and its outputs can drive an inductive load in common or differenzial mode, depending on the state of the inputs. The current that flows through the load comes out from the bridge at the sense output : an external resistor (RSA ; RSB.) allows to detect the intensity of this current.
1.2. INPUT STAGE
Each bridge is driven by means of four gates the input of which are In1 ; In2 ; EnA and In3 ; In4 ; EnB. The In inputs set the bridge state when The En input is high ; a low state of the En input inhibits the bridge. All the inputs are TTL compatible.
2. SUGGESTIONS
A non inductive capacitor, usually of 100 nF, must be foreseen between both Vs and Vss, to ground, as near as possible to GND pin. When the large capacitor of the power supply is too far from the IC, a second smaller one must be foreseen near the L298.
The sense resistor, not of a wire wound type, must be grounded near the negative pole of Vs that must be near the GND pin of the I.C.

Each input must be connected to the source of the driving signals by means of a very short path. Turn-On and Turn-Off : Before to Turn-ON the Supply Voltage and before to Turn it OFF, the Enable input must be driven to the Low state.
3. APPLICATIONS
Fig 6 shows a bidirectional DC motor control Schematic Diagram for which only one bridge is needed. The external bridge of diodes D1 to D4 is made by four fast recovery elements (trr ≤ 200 nsec) that must be chosen of a VF as low as possible at the worst case of the load current.
The sense output voltage can be used to control the current amplitude by chopping the inputs, or to provide overcurrent protection by switching low the enable input.
The brake function (Fast motor stop) requires that the Absolute Maximum Rating of 2 Amps must never be overcome.
When the repetitive peak current needed from the load is higher than 2 Amps, a paralleled configuration can be chosen (See Fig.7).
An external bridge of diodes are required when inductive loads are driven and when the inputs of the IC are chopped ; Shottky diodes would be preferred.

L298

7/13

This solution can drive until 3 Amps In DC operation and until 3.5 Amps of a repetitive peak current.
On Fig 8 it is shown the driving of a two phase bipolar stepper motor ; the needed signals to drive the inputs of the L298 are generated, in this example, from the IC L297.
Fig 9 shows an example of P.C.B. designed for the application of Fig 8.

Fig 10 shows a second two phase bipolar stepper motor control circuit where the current is controlled by the I.C. L6506.

Figure 8 : Two Phase Bipolar Stepper Motor Circuit.
This circuit drives bipolar stepper motors with winding currents up to 2 A. The diodes are fast 2 A types.

trr ≤ 200 ns

D1 to D8 = 2 A Fast diodes { VF ≤ 1.2 V @ I = 2 A

L298

8/13


Figure 9 : Suggested Printed Circuit Board Layout for the Circuit of fig. 8 (1:1 scale).

Figure 10 : Two Phase Bipolar Stepper Motor Control Circuit by Using the Current Controller L6506.

RR and Rsense depend from the load current

Multiwatt15 V; DIM.; inch; OUTLINE AND MECHANICAL DATA

MIN. | TYP. | MAX. | MIN. | TYP. | MAX.
A | | | 5 | | | 0.197
B | | | 2.65 | | | 0.104
C | | | 1.6 | | | 0.063
D | | 1 | | | 0.039
E | 0.49 | | 0.55 | 0.019 | | 0.022
F | 0.66 | | 0.75 | 0.026 | | 0.030
G | 1.02 | 1.27 | 1.52 | 0.040 | 0.050 | 0.060
G1 | 17.53 | 17.78 | 18.03 | 0.690 | 0.700 | 0.710
H1 | 19.6 | | | 0.772
H2 | | | 20.2 | | | 0.795
L | 21.9 | 22.2 | 22.5 | 0.862 | 0.874 | 0.886
L1 | 21.7 | 22.1 | 22.5 | 0.854 | 0.870 | 0.886
L2 | 17.65 | | 18.1 | 0.695 | | 0.713
L3 | 17.25 | 17.5 | 17.75 | 0.679 | 0.689 | 0.699
L4 | 10.3 | 10.7 | 10.9 | 0.406 | 0.421 | 0.429
L7 | 2.65 | | 2.9 | 0.104 | | 0.114
M | 4.25 | 4.55 | 4.85 | 0.167 | 0.179 | 0.191
M1 | 4.63 | 5.08 | 5.53 | 0.182 | 0.200 | 0.218
S | 1.9 | | 2.6 | 0.075 | | 0.102
S1 | 1.9 | | 2.6 | 0.075 | | 0.102
Dia1 | 3.65 | | 3.85 | 0.144 | | 0.152


MIN. | TYP. | MAX. | MIN. | TYP. | MAX.
A | | | 5 | | | 0.197
B | | | 2.65 | | | 0.104
C | | | 1.6 | | | 0.063
E | 0.49 | | 0.55 | 0.019 | | 0.022
F | 0.66 | | 0.75 | 0.026 | | 0.030
G | 1.14 | 1.27 | 1.4 | 0.045 | 0.050 | 0.055
G1 | 17.57 | 17.78 | 17.91 | 0.692 | 0.700 | 0.705
H1 | 19.6 | | | 0.772
H2 | | | 20.2 | | | 0.795
L | | 20.57 | | | 0.810
L1 | | 18.03 | | | 0.710
L2 | | 2.54 | | | 0.100
L3 | 17.25 | 17.5 | 17.75 | 0.679 | 0.689 | 0.699
L4 | 10.3 | 10.7 | 10.9 | 0.406 | 0.421 | 0.429
L5 | | 5.28 | | | 0.208
L6 | | 2.38 | | | 0.094
L7 | 2.65 | | 2.9 | 0.104 | | 0.114
S | 1.9 | | 2.6 | 0.075 | | 0.102
S1 | 1.9 | | 2.6 | 0.075 | | 0.102
Dia1 | 3.65 | | 3.85 | 0.144 | | 0.152

JEDEC MO-166; PowerSO20; PSO20MEC; DETAIL A; DETAIL A lead; slug a3; Gage Plane; DETAIL B; (COPLANARITY); SEATING PLANE; BOTTOM VIEW; DIM.; inch; OUTLINE AND MECHANICAL DATA

MIN. | TYP. | MAX. | MIN. | TYP. | MAX.
A | | | 3.6 | | | 0.142
a1 | 0.1 | | 0.3 | 0.004 | | 0.012
a2 | | | 3.3 | | | 0.130

b | 0.4 | | 0.53 | 0.016 | | 0.021
c | 0.23 | | 0.32 | 0.009 | | 0.013
D (1) | 15.8 | | 16 | 0.622 | | 0.630
D1 | 9.4 | | 9.8 | 0.370 | | 0.386
E | 13.9 | | 14.5 | 0.547 | | 0.570
e | | 1.27 | | | 0.050
e3 | | 11.43 | | | 0.450
E1 (1) | 10.9 | | 11.1 | 0.429 | | 0.437
E2 | | | 2.9 | | | 0.114
E3 | 5.8 | | 6.2 | 0.228 | | 0.244
G | 0 | | 0.1 | 0.000 | | 0.004
H | 15.5 | | 15.9 | 0.610 | | 0.626
h | | | 1.1 | | | 0.043
L | 0.8 | | 1.1 | 0.031 | | 0.043
N | 10˚ (max.)
S | 8˚ (max.)
T | | 10 | | | 0.394

(1) "D and F" do not include mold flash or protrusions.
- Mold flash or protrusions shall not exceed 0.15 mm (0.006").
- Critical dimensions: "E", "G" and "a3"

Information furnished is believed to be accurate and reliable. However, STMicroelectronics assumes no responsibility for the consequences of use of such information nor for any infringement of patents or other rights of third parties which may result from its use. No license is granted by implication or otherwise under any patent or patent rights of STMicroelectronics. Specification mentioned in this publication are subject to change without notice. This publication supersedes and replaces all information previously supplied. STMicroelectronics products are not authorized for use as critical components in life support devices or systems without express written approval of STMicroelectronics.
The ST logo is a registered trademark of STMicroelectronics
© 2000 STMicroelectronics – Printed in Italy – All Rights Reserved STMicroelectronics GROUP OF COMPANIES Australia - Brazil - China - Finland - France - Germany - Hong Kong - India - Italy - Japan - Malaysia - Malta - Morocco -Singapore - Spain - Sweden - Switzerland - United Kingdom - U.S.A. http://www.st.com

L298

13/13

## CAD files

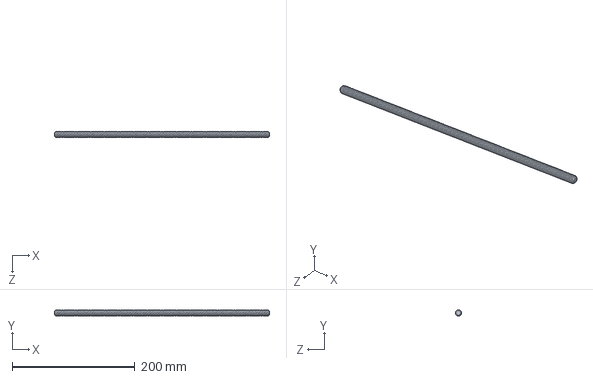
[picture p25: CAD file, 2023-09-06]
MechanicalFiles/SinFin.SLDPRT
350.0 x 10.0 x 10.0 mm

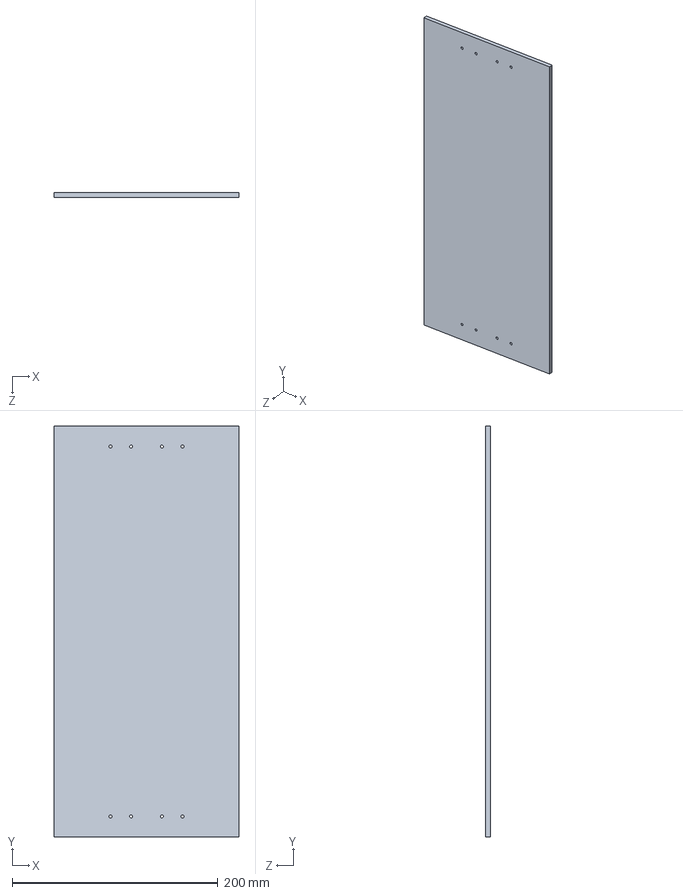
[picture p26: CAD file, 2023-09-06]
MechanicalFiles/placa.STEP
180.0 x 400.0 x 5.00 mm

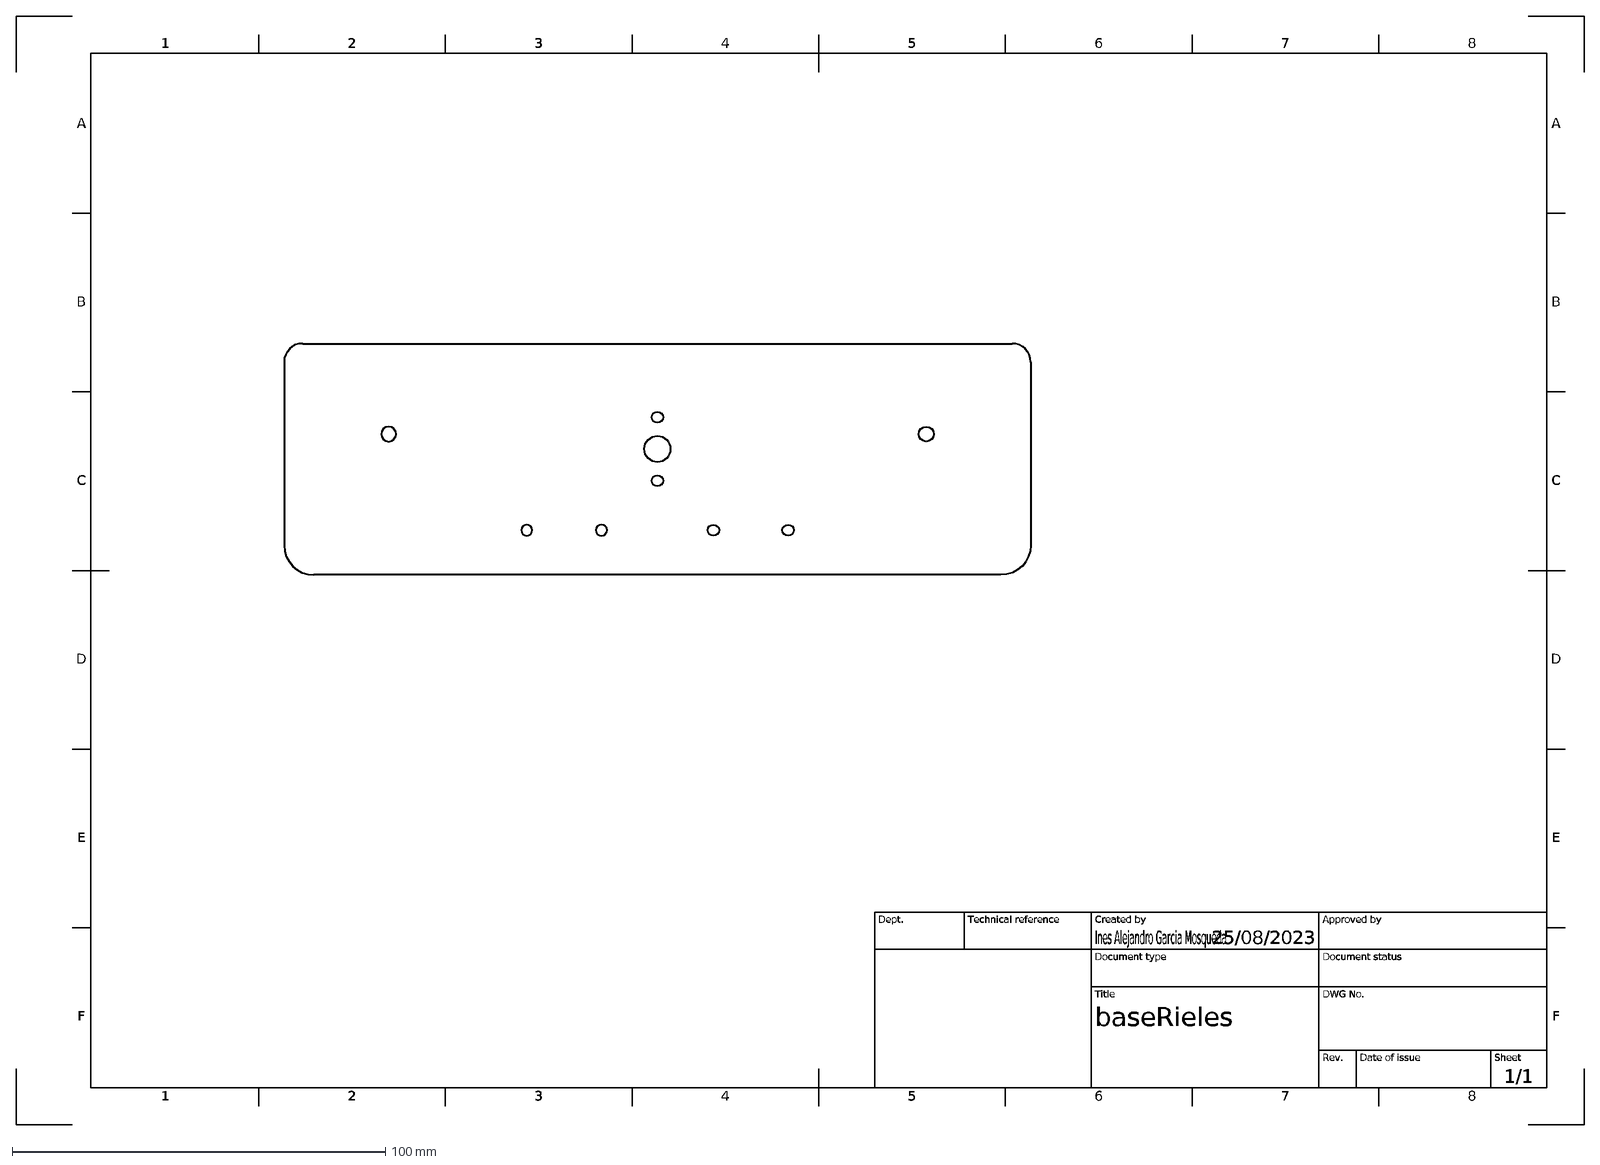
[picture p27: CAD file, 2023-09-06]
MechanicalFiles/placaConMotor.dxf
1
A
2
3
4
5
6
7
8
B
C
D
E
F
25/08/2023
1/1
baseRieles
Ines Alejandro Garcia Mosqueda
Dept.
Technical reference
Created by
Approved by
Document type
Document status
Title
DWG No.
Rev.
Date of issue
Sheet

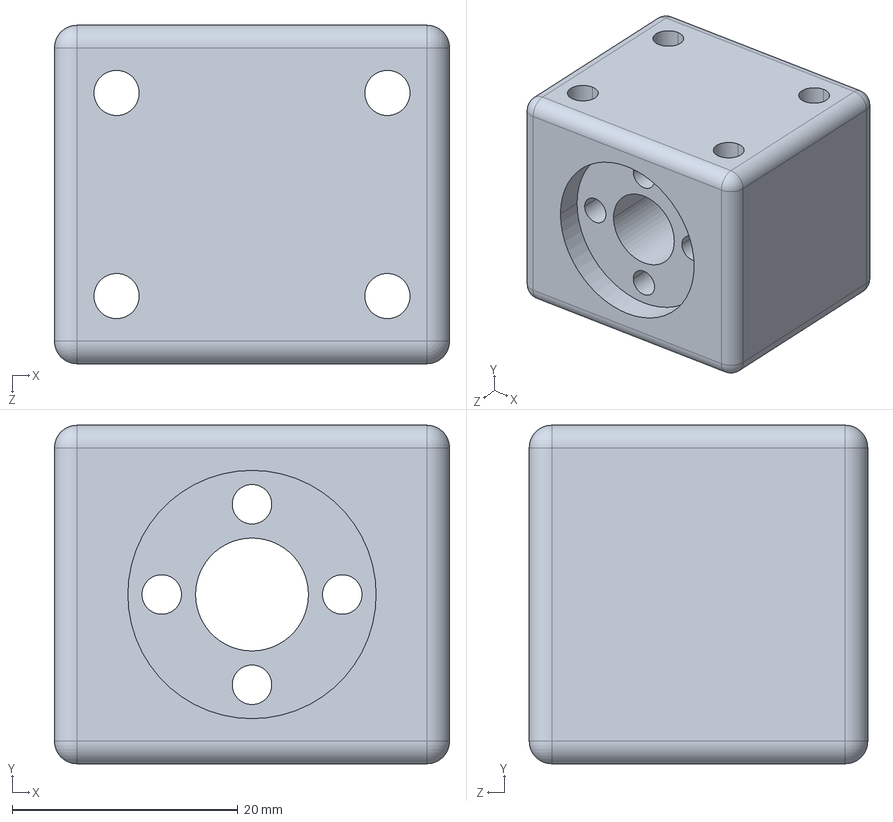
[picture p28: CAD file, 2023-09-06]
MechanicalFiles/CamisaTuercaHusillo.STEP
35.0 x 30.0 x 30.0 mm

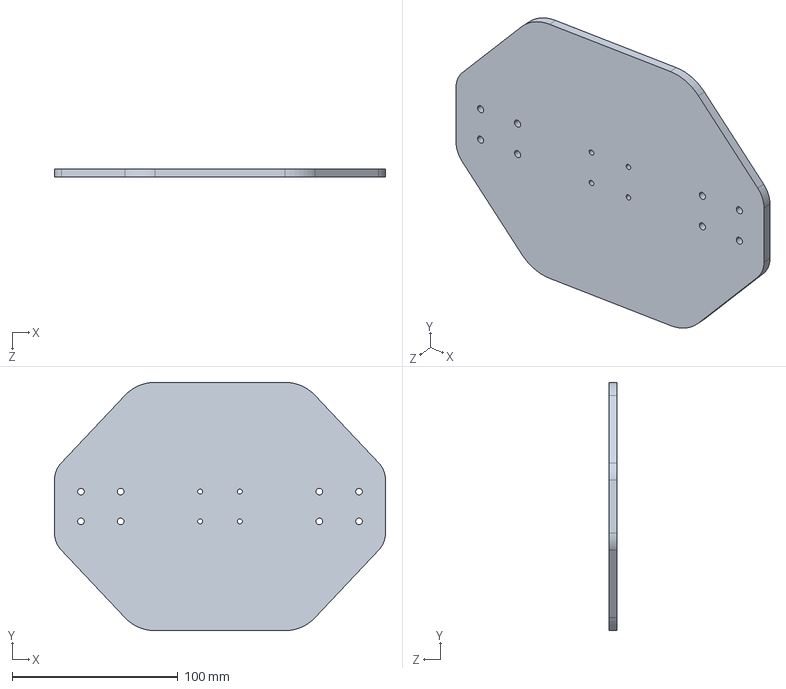
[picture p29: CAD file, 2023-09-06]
MechanicalFiles/carrito eje.STEP
200.0 x 150.1 x 5.00 mm

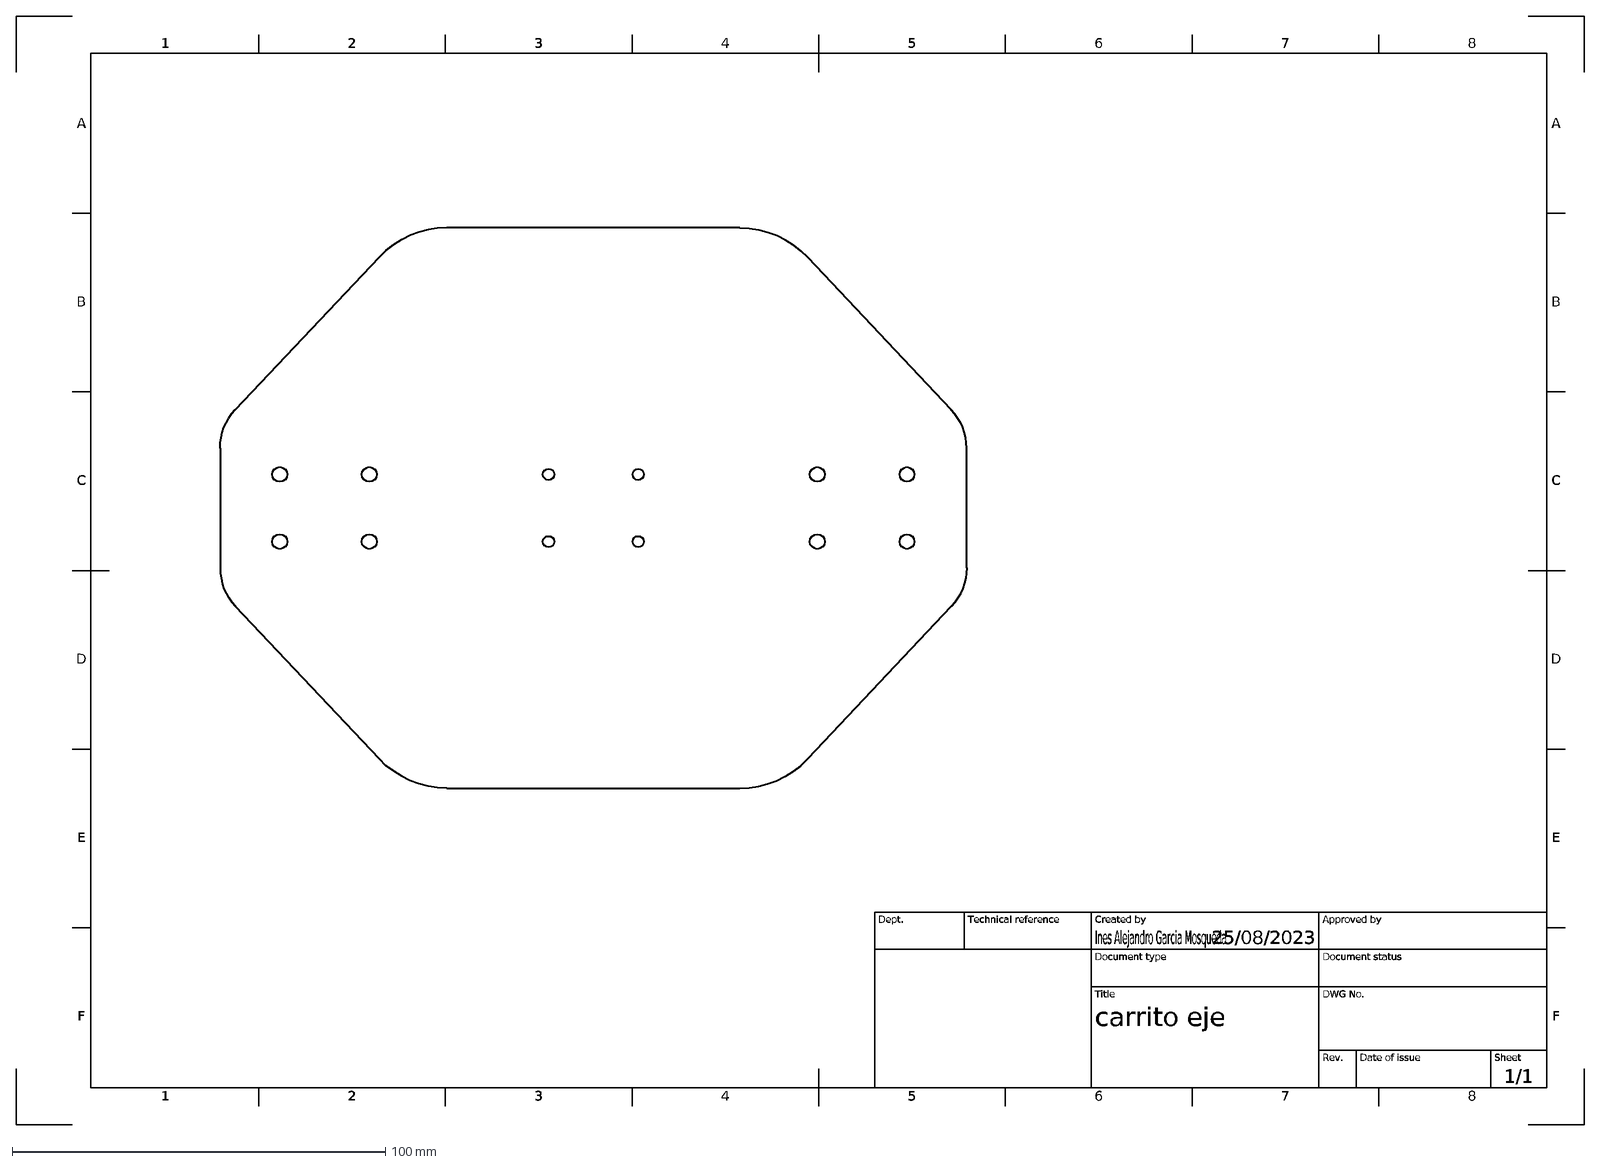
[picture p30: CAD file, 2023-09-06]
MechanicalFiles/ejeEje.dxf
1
A
2
3
4
5
6
7
8
B
C
D
E
F
25/08/2023
1/1
carrito eje
Ines Alejandro Garcia Mosqueda
Dept.
Technical reference
Created by
Approved by
Document type
Document status
Title
DWG No.
Rev.
Date of issue
Sheet

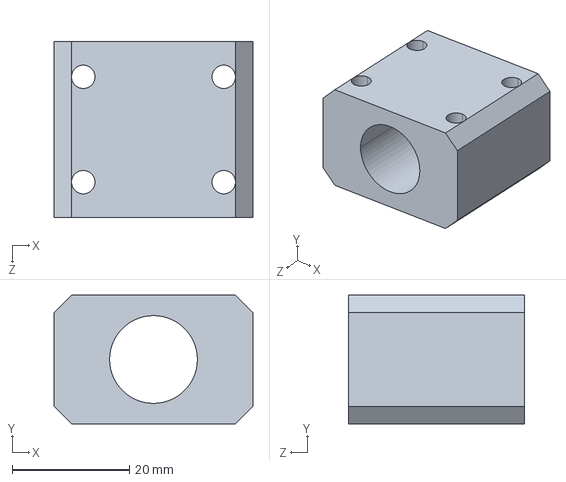
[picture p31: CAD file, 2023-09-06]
MechanicalFiles/CamisaBaleroLineal.STEP
34.0 x 22.0 x 30.0 mm

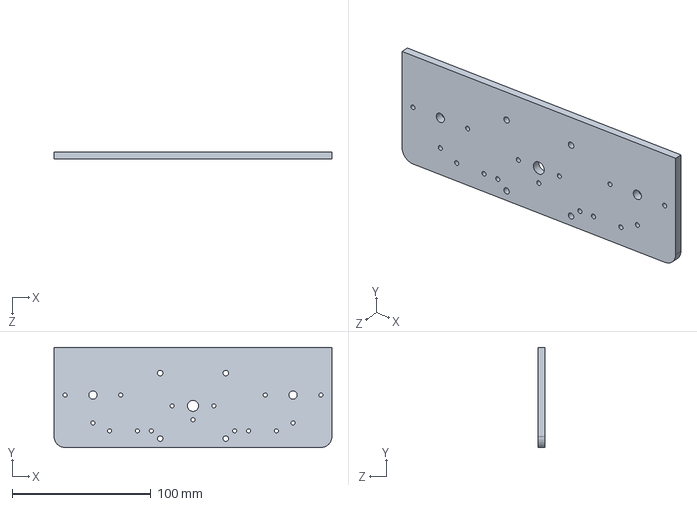
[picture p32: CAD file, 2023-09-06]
MechanicalFiles/baseRielesMotor.SLDPRT
200.0 x 72.0 x 5.00 mm

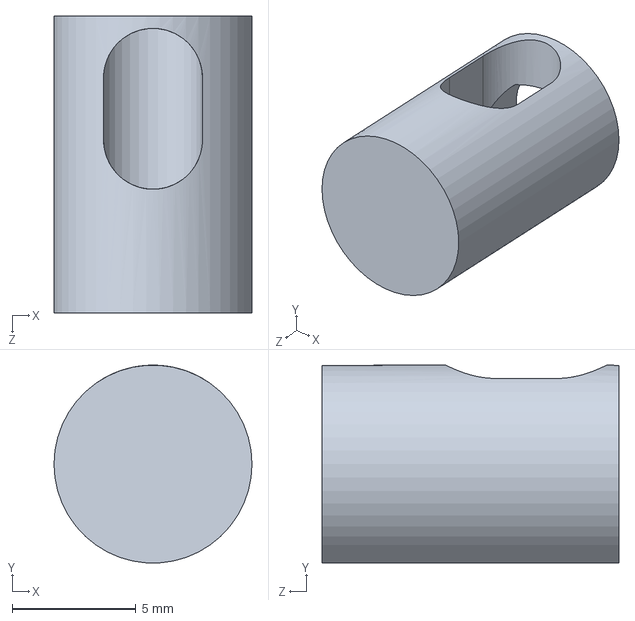
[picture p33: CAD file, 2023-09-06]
MechanicalFiles/Bujemotor.SLDPRT
8.00 x 7.99 x 12.0 mm

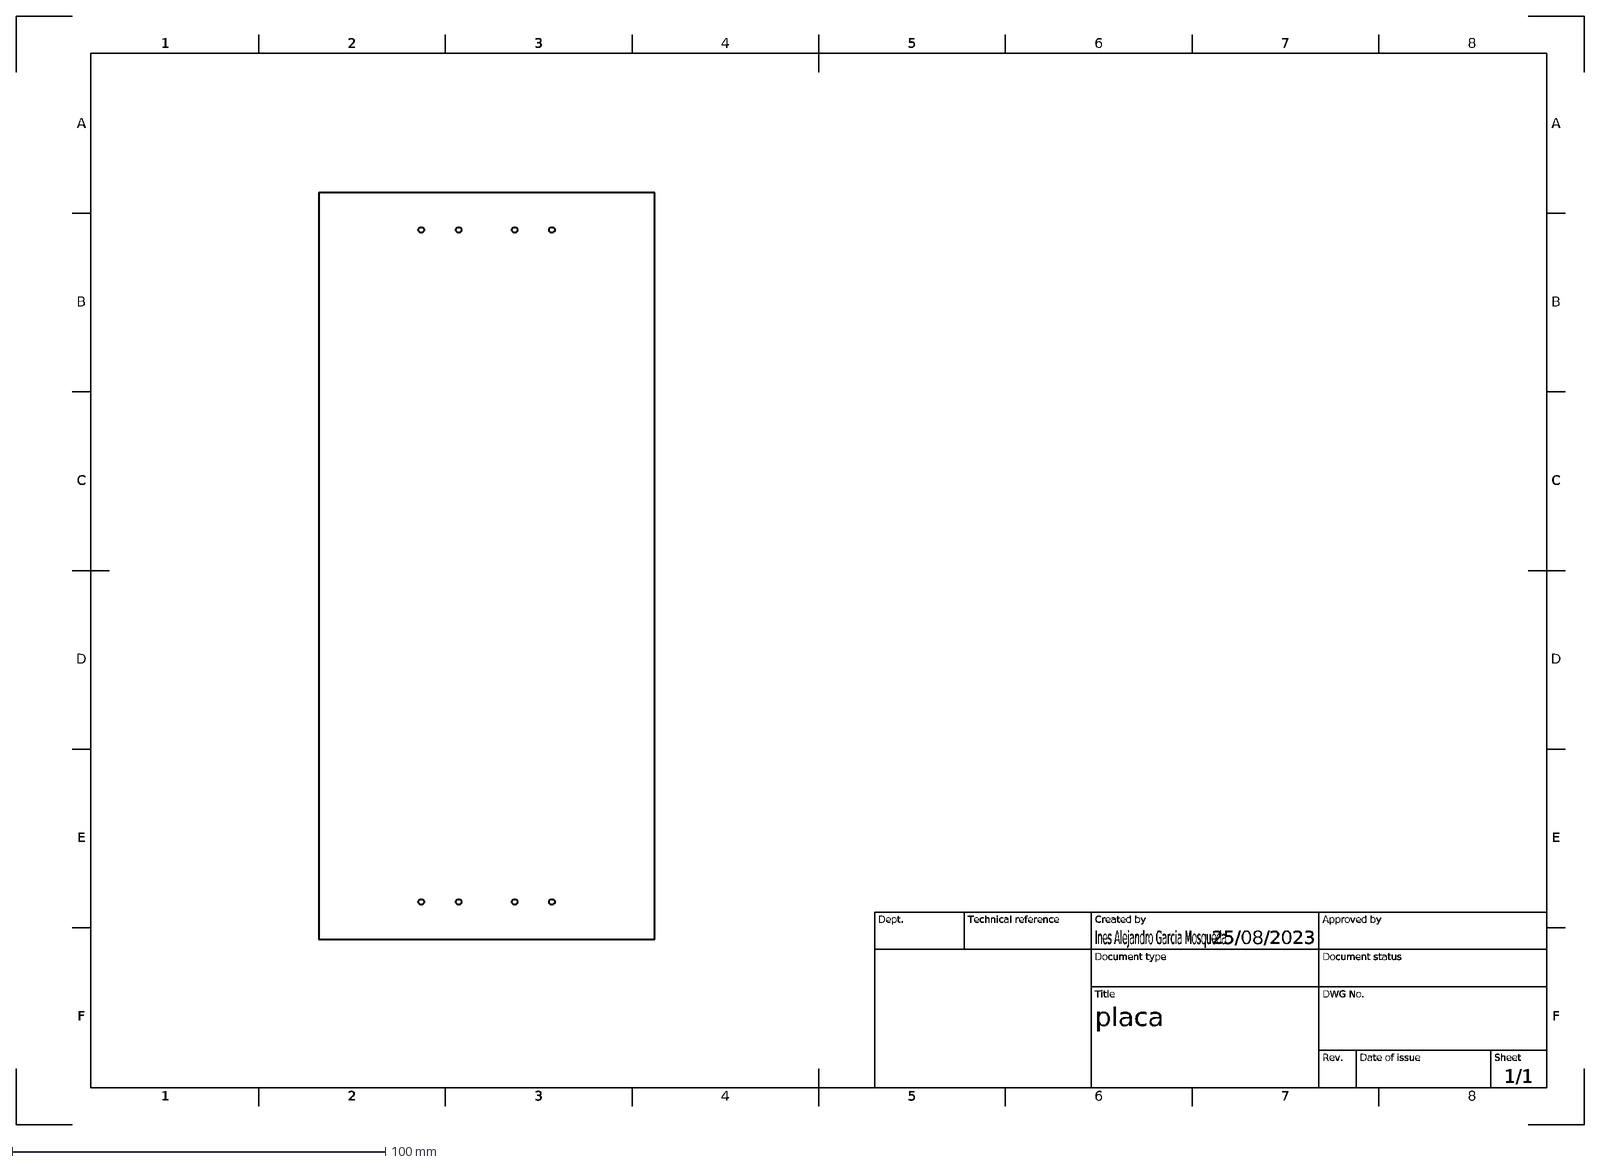
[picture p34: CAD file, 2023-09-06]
MechanicalFiles/placaPlaca.dxf
1
A
2
3
4
5
6
7
8
B
C
D
E
F
25/08/2023
1/1
placa
Ines Alejandro Garcia Mosqueda
Dept.
Technical reference
Created by
Approved by
Document type
Document status
Title
DWG No.
Rev.
Date of issue
Sheet

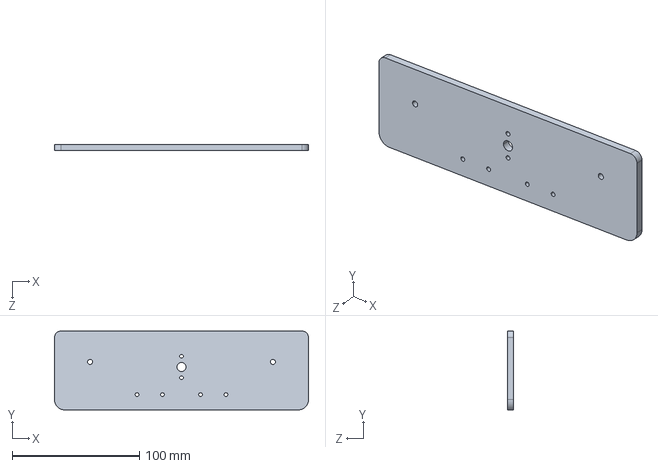
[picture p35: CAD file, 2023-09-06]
MechanicalFiles/baseRieles.STEP
200.0 x 62.0 x 5.00 mm

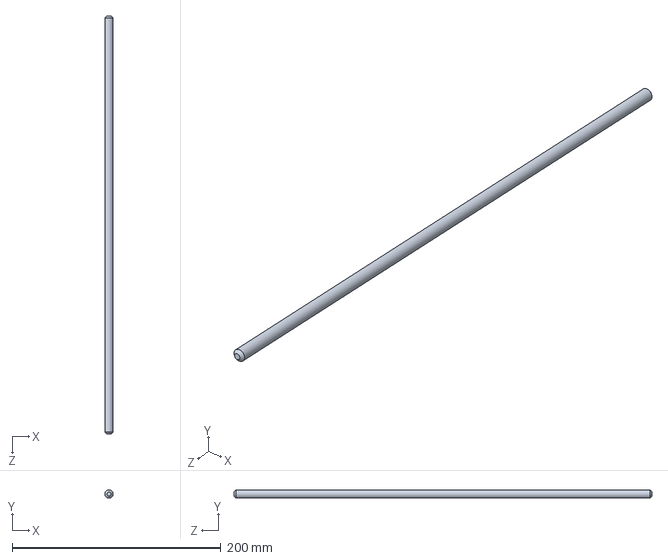
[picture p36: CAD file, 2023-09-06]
MechanicalFiles/varillaLisa.SLDPRT
8.00 x 8.00 x 400.0 mm

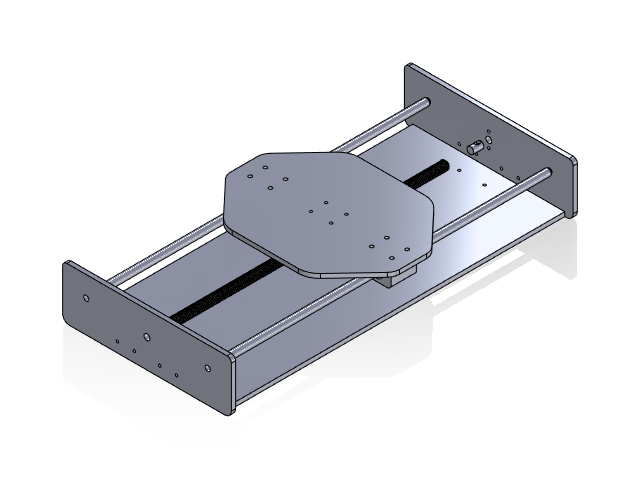
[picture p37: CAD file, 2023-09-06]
MechanicalFiles/EjeLineal.SLDASM
placa
baseRieles x 2
SinFin
varillaLisa x 2
carrito eje y 2
CamisaBaleroLineal x 2
CamisaTuercaHusillo
Bujemotor

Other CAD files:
MechanicalFiles/Planos Chasis e impresiones.dwg
MechanicalFiles/carrito eje y 2.SLDPRT
MechanicalFiles/Bujemotor.STL
MechanicalFiles/CamisaBaleroLineal.SLDPRT
MechanicalFiles/CamisaTuercaHusillo.SLDPRT
MechanicalFiles/baseRieles.SLDPRT
MechanicalFiles/placa.SLDPRT

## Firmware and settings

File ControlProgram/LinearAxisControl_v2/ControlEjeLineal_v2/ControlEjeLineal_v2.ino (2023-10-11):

//Archivo Arduino
#include "PositionMotorControl.h"


// Definición de constantes mecanicas
const float MAX_DISTANCE_MM = 1000.0;       // Distancia máxima en milímetros
const float PULSES_PER_REVOLUTION = 493.9; // Pulsos por revolución del encoder
const float MM_PER_REVOLUTION = 8.0; 

// Calcula el ángulo máximo en grados correspondiente a la distancia máxima
const float MAX_ANGLE_DEGREES = (MAX_DISTANCE_MM / MM_PER_REVOLUTION) * 360.0;
const float MAX_POT_VALUE = 1023;

//Definicion de pines del driver
const int motorPin1 = 4;  //PWM
const int motorPin2 = 5;  //Direccion
const int motorPin3 = 6;  //Direccion2

const int encoderAPin = 2;
const int encoderBPin = 3;
const int potentiometerPin = A0;

float angle_degrees = 0;
long pulses = 0;

PositionMotorControl motor(motorPin1, motorPin2, motorPin3, encoderAPin, encoderBPin, MAX_DISTANCE_MM, PULSES_PER_REVOLUTION, MM_PER_REVOLUTION);

void setup() {
  Serial.begin(9600);
  motor.init();
  motor.setVelocity(0);
}

void loop() {


  if(Serial.available()){
    String aux = Serial.readStringUntil('\n');
    if(aux=="set"){
      motor.setCero();
      angle_degrees = 0;
      
    }
    else{
      //angle_degrees = PULSES_PER_REVOLUTION * String(aux).toFloat()* 0.9076 ;
      angle_degrees = String(aux).toFloat()* 2 * 3.1416 * 0.9076 ;
      pulses = angle_degrees / MM_PER_REVOLUTION ;
      Serial.print(angle_degrees);
      Serial.print(" -> ");
    }
  }
  
  Serial.println(motor.getCurrentPos());
  Serial.print(" -> ");
  Serial.print(pulses);
  Serial.print(" -> cv ");
  Serial.println(motor.getVelocity());
  //Serial.print(" -> nv");
  //Serial.print(motor.getVelocity());
  

  // Establecer la posición objetivo del motor en pulsos
  motor.setTargetPosition(pulses);

  //Algoritmo de control
  motor.controlPID();
}

float readPot(int potPin){
  // Leer el valor del potenciómetro
  int potValue = analogRead(potentiometerPin);
  
  // Calculo del ángulo objetivo en grados
  float angle_degrees = map(potValue, 0, MAX_POT_VALUE, 0, MAX_ANGLE_DEGREES);

  // Calculo de cantidad de pulsos objetivo en función del ángulo
  float pulses_target = angle_degrees * (PULSES_PER_REVOLUTION / 360.0);

  Serial.println(pulses_target);

  return pulses_target;
}

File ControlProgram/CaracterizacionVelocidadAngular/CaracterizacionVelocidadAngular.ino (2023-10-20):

////////////////////////////////////////////
//Programa identificacion motor
////Oliver hernández
///////////////////////////////////////////

#include<TimerOne.h>
///Declar pines
const int Pin_1A = 5; /// dato de direccion 
const int Pin_2A = 6; /// dato de direccion
const int Pin_EN = 4; /// Enable PWM
///////////////////////////////////////////
const int interruptPin = 3; ///// Pin DE INTERRUPCION
long unsigned int counter = 0;
int DutyCycle = 0; ///Valor Pwm DE 0-255
double Velocidad_en_RPM = 0.0; ///
float tiempo = 0.0; 

void setup() {
  pinMode(Pin_1A,OUTPUT);
  pinMode(Pin_2A,OUTPUT);
  pinMode(Pin_EN,OUTPUT);
  pinMode(interruptPin,INPUT);
//Giro del motor
  digitalWrite(Pin_1A,LOW);
  digitalWrite(Pin_2A,HIGH);
  attachInterrupt(digitalPinToInterrupt(interruptPin), counting, RISING);
  Timer1.initialize(20000);
  Timer1.attachInterrupt(ISR_RevolucionesPorMinuto);
  Serial.begin(9600);
  Serial.println("LABEL,pwm,posicion");
}

void loop() {
  DutyCycle=random(100,255); //Señal PWM aletatorio 
  analogWrite(Pin_EN,DutyCycle);
  delay(random(100,200));
}
  ////////////////////////////////////////////////
  ///Funciones
void counting(){
  ////Contador
  counter++;
  }
  void ISR_RevolucionesPorMinuto(){
    ///Velocidad(RPM)= 60*counter/resolucion*Ts
    Velocidad_en_RPM = 60*counter/(493.9*0.02);
    tiempo = tiempo + 0.02;
    Serial.print("DATA,");
    Serial.print(DutyCycle);
    Serial.print(",");
    Serial.println(Velocidad_en_RPM);
    //counter = 0;
   }

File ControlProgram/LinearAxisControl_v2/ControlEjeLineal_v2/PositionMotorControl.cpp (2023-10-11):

//Definicion de fiunciones control de posicion
#include "PositionMotorControl.h"

PositionMotorControl* motorInstance;

PositionMotorControl::PositionMotorControl(int motorPin1, int motorPin2, int motorPin3, int encoderAPin, int encoderBPin, float maxDistanceMM, float pulsesPerRevolution, float mmPerRevolution)
  : motorPin1(motorPin1), motorPin2(motorPin2), motorPin3(motorPin3), encoderAPin(encoderAPin), encoderBPin(encoderBPin), maxDistanceMM(maxDistanceMM), pulsesPerRevolution(pulsesPerRevolution), mmPerRevolution(mmPerRevolution) {
    targetPosition = 0;
    currentPosition = 0.0;
    motorSpeed = 0;
    error = 0;
    motorInstance = this;
}

void PositionMotorControl::init() {
  // Declaracion de salidas y entradas
  pinMode(motorPin1, OUTPUT);
  pinMode(motorPin2, OUTPUT);
  pinMode(motorPin3, OUTPUT);
  pinMode(encoderAPin, INPUT_PULLUP);
  pinMode(encoderBPin, INPUT_PULLUP);

  // Declaracion de interrupciones a encoders
  attachInterrupt(digitalPinToInterrupt(encoderAPin), handleEncoderStatic, CHANGE);
  // attachInterrupt(digitalPinToInterrupt(encoderBPin), handleEncoderStatic, CHANGE);

  motorSpeed = 200;
  prevPwm = 0;
}

void PositionMotorControl::control()
{
  int pwmSpeed;
  error = targetPosition - currentPosition;
  
  // Comparison between direction and velocity
  if (error <= -15) {
    motorDirection = 1; // Move forward
    pwmSpeed = motorSpeed;
  }
  else if (error >= 15) {
    motorDirection = -1; // Move backward
    pwmSpeed = motorSpeed;
  }
  else {
    motorDirection = 0; // Stop
    pwmSpeed = 0;
  }

  // Motor's control
  analogWrite(motorPin1, pwmSpeed);
  digitalWrite(motorPin2, motorDirection == -1 ? HIGH : LOW);
  digitalWrite(motorPin3, motorDirection == 1 ? HIGH : LOW);
}

void PositionMotorControl::controlPID(){
  error = targetPosition - (currentPosition * 2 * 3.1416 / 493.9);
  errores[1] = errores[0];
  errores[2] = errores[1];
  errores[0] = error;
  prevPwm = motorSpeed;
  //double kp = 1.5;
  //double ki = 2;
  //double kd = 0.005;
  
  double kp = 248;
  double ki = 2300;
  double kd = 7.44;
  double a = (kp + kd/0.02) * errores[0];
  double b = (-kp + (ki*0.02) - (2*kd/0.02)) * errores[1];
  double c = (kd/0.02) * errores[2];

  int pwmSpeed = prevPwm + a + b + c;
  motorSpeed = pwmSpeed;


  // Comparison between direction and velocity
  if (error <= -1) {
    motorDirection = 1; // Move forward
  }
  else if (error >= 1) {
    motorDirection = -1; // Move backward
  }
  else {
    motorDirection = 0; // Stop
    pwmSpeed = 0;
  }

    // Motor's control
  analogWrite(motorPin1, motorSpeed);
  digitalWrite(motorPin2, motorDirection == -1 ? HIGH : LOW);
  digitalWrite(motorPin3, motorDirection == 1 ? HIGH : LOW);
  
 }

// Set de posicion del motor
void PositionMotorControl::setTargetPosition(long nPulses) {
  targetPosition = nPulses;
}

int PositionMotorControl::getCurrentPos(){
  return currentPosition;  
}

void PositionMotorControl::setCero(){
  currentPosition = 0;
  targetPosition = 0;
}

void PositionMotorControl::setVelocity(int pwm){
  motorSpeed = pwm;
}

int PositionMotorControl::getVelocity(){
  return motorSpeed;
}

// Funcion estatica para manejo de interrupcion
static void PositionMotorControl::handleEncoderStatic() {
  motorInstance->handleEncoder(); // Llamada de funcion no estatica de la instancia
}

void PositionMotorControl::handleEncoder() {
  encoderAState = digitalRead(encoderAPin);
  encoderBState = digitalRead(encoderBPin);
  
  // Determinacion de la dirección del giro del motor
  if (encoderAState == encoderBState ) {
    currentPosition --;
    motorDirection = -1;
  }
  else
  {
    currentPosition ++;
    motorDirection = 1;
  } 
  
}

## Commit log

2023-09-06 Mechanics & control
    Mechanical design / Control Program v1
    [Bujemotor.SLDPRT, Bujemotor.STL, CamisaBaleroLineal.SLDPRT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]
2023-09-07 control de propocion v1
2023-10-11 Implementación PID
